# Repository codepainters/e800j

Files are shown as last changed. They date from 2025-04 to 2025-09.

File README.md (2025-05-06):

# Elwro 800 Junior replica

This repository contains all the necessary files to build a replica of [Elwro 800 Junior](https://pl.wikipedia.org/wiki/Elwro_800_Junior), a Polish home computer that can be considered a  [ZX Spectrum](https://en.wikipedia.org/wiki/ZX_Spectrum) clone. As of May 5, 2025, there are 3 successful builds, so the design files can be assumed valid.

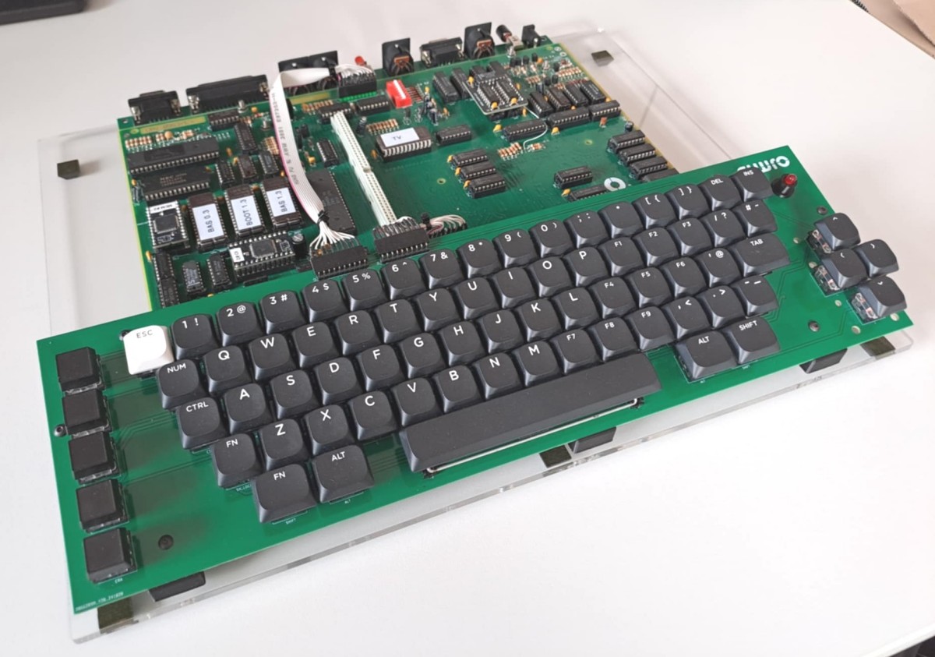
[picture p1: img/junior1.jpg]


## PCBs

The replica consists of three separate PCBs:

* [e800j_rev_c](e800j_rev_c) is the main board, an exact clone of the original *Elwro 800 Junior Rev C* PCB.  The original dimensions and mounting holes have been precisely recreated, making it suitable as a direct replacement for damaged original boards. 
* [kbd_cherry](kbd_cherry) is a replacement keyboard that uses standard Cherry MX switches. I chose not to replicate the original keyboard, as its switches are nearly impossible to source.
* [ports_pcb](ports_pcb) is a ports breakout board designed to simplify connections and avoid the mess of individual wires. This board is optional, but if you choose to connect ports with wires (as in the original design), you’ll need to derive the connections from the schematics.

All boards were designed in KiCad 9. In addition to the KiCad project files, each directory includes Gerber files, an interactive BOM, and PDF schematics. Refer to the respective subdirectories for assembly instructions and details.

### Additional documentation

* [pinouts](docs/pinouts.md) of the connectors
* [scans](docs/scans/) of the original schematics and DTR (*dokumentacja techniczno-ruchowa* - Polish for *technical reference manual*)
* [SCART](docs/scart.md) cable schematics / discussion

## Side projects

* Several side projects were created alongside the main replica (hosted in separate repositories):
* [e800j_addr_dec_gal](https://github.com/codepainters/e800j_addr_dec_gal) - replacement for address decoder PROMs using `GAL16V8` (original `74S474` PROMs are hard to get)
* [e800j_addr_dec_atf](https://github.com/codepainters/e800j_addr_dec_atf) - SMT variant using `ATF1502ASL`
* [e800j_grafix](https://github.com/codepainters/e800j_grafix) - a small add-on board that fixes graphics glitches present in the original Elwro design
* [JuDIM](https://github.com/codepainters/judim) - Junior Disk Manager, a small CLI tool for transferring files to/from `DSK` images (similar in principle to [cpmtools](https://www.moria.de/~michael/cpmtools/))

More to follow.

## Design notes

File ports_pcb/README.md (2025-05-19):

# Ports breakout PCB for the Elwro 800 Junior replica

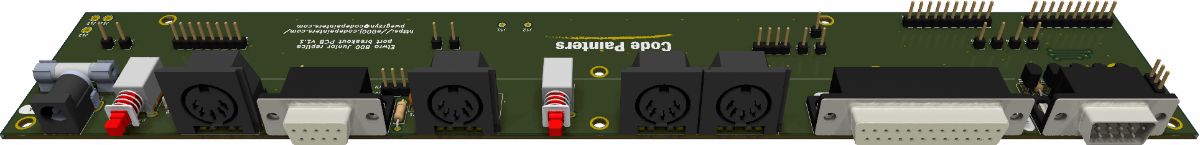
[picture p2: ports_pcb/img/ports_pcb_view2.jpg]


The idea behind this board is to simplify building the Junior replica (and not only that; read the notes section below), by using PCB-mounted connectors and switches, thus avoiding all the messy wire connections, as done in the original *Elwro 800 Junior*:

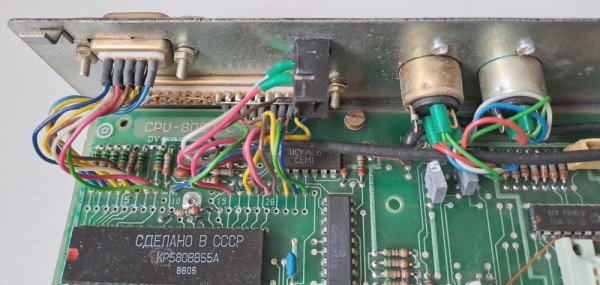
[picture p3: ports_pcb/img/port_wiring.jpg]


## Files

This directory contains the KiCAD 9 project, plus:

* schematics in PDF format - [color](ports_pcb.pdf) and [b&w](ports_pcb_bw.pdf)
* interactive [BOM](ports_pcb_ibom.html) (you need to download the file and open it locally) 
* [Gerber](gerbers) files (JLCPCB-compatible)

## Assembly

It's best to follow the interactive [BOM](ports_pcb_ibom.html).

### Options

There are some choices to be made:

* the original *Elwro* expects the joystick to short pins 1, 2, 3, 4 and 6 to `+5V` (and not to `GND`, as is usually done). 
  Because of this, pin 8 of the joystick connector is connected to the `+5V` rail.

  I decided to add 5 simple inverters (each consisting of a PNP transistor and a resistor) to make the port more standards-compliant 
  (allowing auto-fire joysticks to work as expected). With this modification pin 8 is tied to `GND`, pin 7 delivers `+5V` (via 
   a 27-ohm resistor on the mainboard), and pins 1, 2, 3, 4 and 6 react to shorting to ground.

  * If you want to use my mod, you need to:

    * assemble `T1..T5` transistors and `R1..R5` resistors

    * short pins 1 and 2 of `JP1` 

  * If you want to be 100% compatible with the original *Junior* instead:

    * solder jumpers instead of `R1..R5` resistors

    * solder jumpers between pins 1 and 2 of `T1..T5`

    * short pins 2 and 3 of `JP1`

* if a SCART cable is used, it is necessary to pull SCART's pin 16 (aka *Fast Blank*) above 1V to switch 
  the TV set to RGB signal. Unfortunately, Junior's RGB connector doesn't include a power pin, and there 
  are no spare pins to use. 

  I decided to make pin 8 of the RGB connector configurable between `SYN_H` and `+5V`, as the `SYN_H` signal is not necessary
  for SCART operation. Similarly, `SYN_V` is not really needed, so I've added `JP3` jumper allowing for disconnecting
  pin 6 and using it for other purposes. Also, `JP4` jumper allows for disconnecting `FON` signal from pin 7 (there's a plan to use pins 6 and 7 for stereo audio from AY-3-8910/12 card).

  So, if you want to use a SCART cable, you most likely want to:

  * assemble `C1` capacitor
  * put a jumper in place of  `R6` (the initial idea was to put a 180-ohm resistor there to limit the fast blank current, but now I think it's better to put it in the cable itself)
  * short pins 1 and 2 of `JP2`

  For a detailed explanation of the SCART issues  (as well as the cable schematics) , see [here](../docs/scart.md).

### Board stacking

The ports breakout PCB is designed to be mounted below the *Junior* main board and secured in place with M3 bolts. Corresponding pads on both the ports and main PCBs have the same labels (`J1` on the ports board should be connected to `J1` on the main board, `J2` to `J2`, etc.) and are positioned above each other (with 4 exceptions, see below), so they can be connected either by soldering short vertical wires (e.g., cut resistor pins, allowing for 5 mm spacing between the PCBs), or using "gold pin" connectors (requiring ~10 mm spacing). 

Here's how the boards look stacked together:

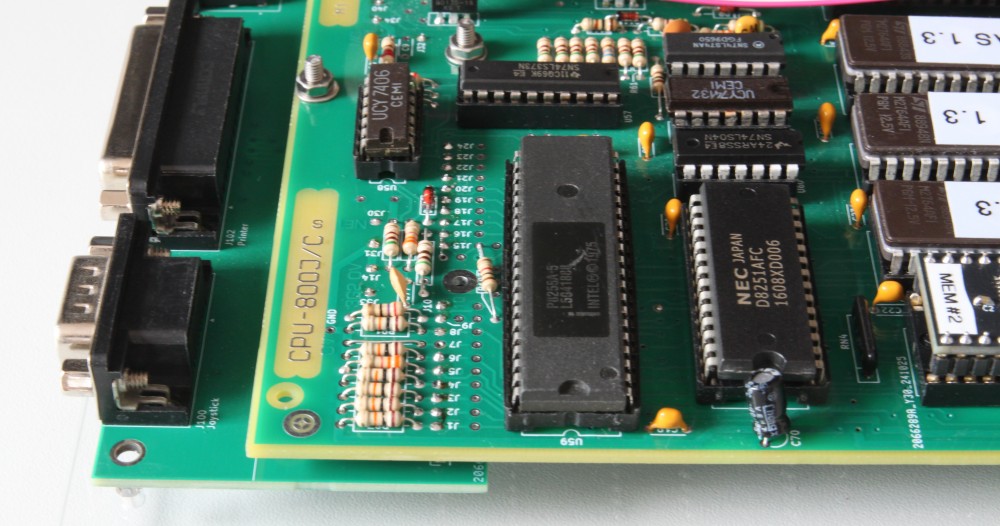
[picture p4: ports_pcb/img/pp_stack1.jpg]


Close-up of the connections:

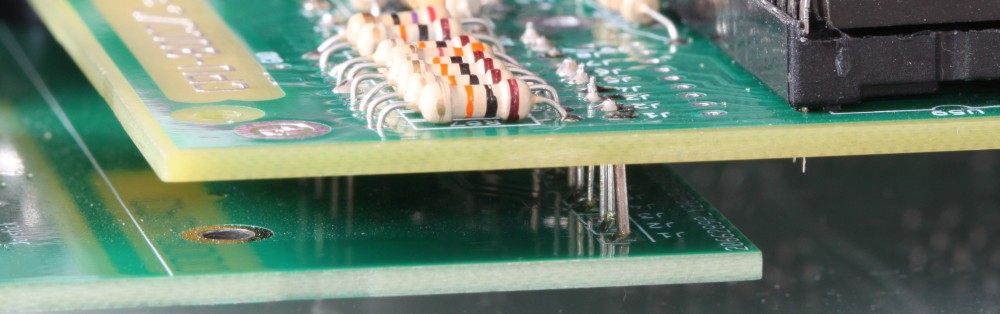
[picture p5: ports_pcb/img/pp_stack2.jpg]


There are the following exceptions that require short insulated wire connections (`J13` can be left unconnected):

* `J41` and `J42` - for the reset button
* `J11` and `J12` - `+5V` and `GND`, respectively

Close-up of the wire connections:

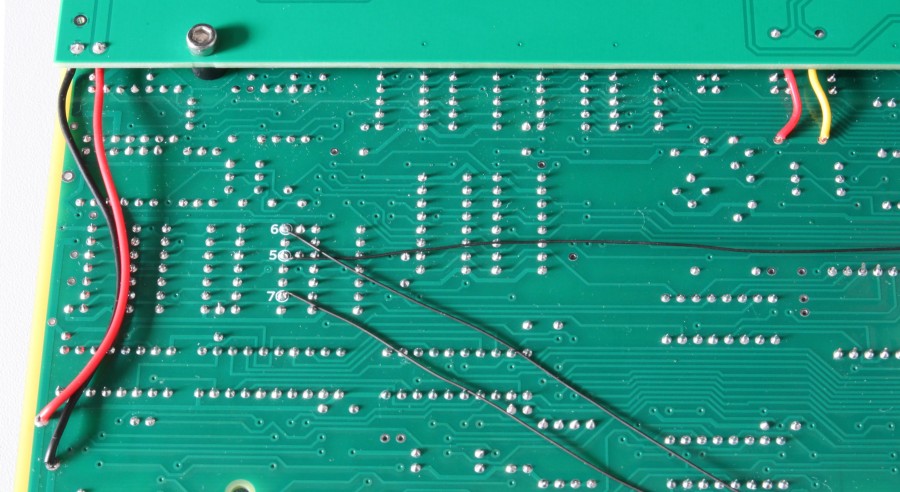
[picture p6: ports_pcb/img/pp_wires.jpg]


## Other Notes

Note that:

* *Elwro 800 Junior* uses a `DB37` connector for the printer, while my board uses the more common `DB25`. This saves a lot of space,
  and standard PC `DB25` printer cables are much easier to find.
* the fuse socket is optional, but I suggest using a fuse - better safe than sorry.

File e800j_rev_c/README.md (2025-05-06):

# Elwro 800 Junior replica - mainboard

This part of the project is the exact clone of the original *Elwro 800 Junior* PCB revision C. The PCB was reverse engineered from scanned images of the original PCB. All dimensions and mounting holes placements have been preserved, so the board can be used as a replacement for the original one.

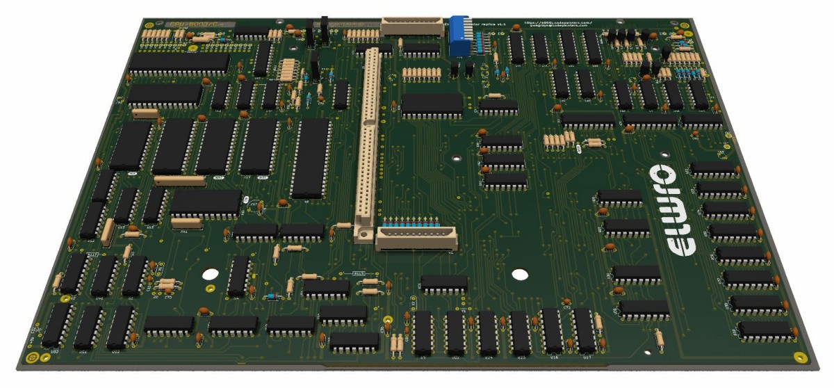
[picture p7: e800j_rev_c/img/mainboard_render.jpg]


Note: **Read this README file carefully**, it contains some important assembly instructions!

## Files

This directory contains the KiCAD 9 project, plus: 

* Schematics in PDF format - [color](pdfs/e800j_rev_c.pdf) and [b&w](pdfs/e800j_rev_bw.pdf) 
* [Gerber](gerbers) files (JLCPCB-compatible zip files)
* Interactive [BOM](e800j_rev_c_ibom.html) (you need to download the file and open it locally) 
* [scans](scans) of the original PCB used for reverse engineering

For files to be programmed into EPROMs, see [here](../roms).

Note: KiCAD PCB file still embeds the scanned images used for reverse engineering, so don't be surprised by the file size! The project passes PCB vs schematic parity check.

## Conventions

Schematics:

* For (hopefully) better readability, original schematic diagram has been split into separate blocks (total of 14 schematic sheets, mostly A4-size, with the exception of address decoder, DRAM, memory controller and video parts, which exceeded A4 size). I believe it's easier to analyze the schematic drawn in this manner. The PCB passes validation against schematic diagrams, so it can be assumed that the schematics are correct.
* In the top-level schematic sheet I decided to only draw some wires / buses between blocks. Global signals (like `MEMR`, or `IOR`) are only connected using labels, as the wires would clutter the drawing too much otherwise.
* Original schematics use somewhat unusual notation for signal names - prefixed with `+` or `-` sign for active-high (e.g. `+RELOK`) and active-low (e.g. `-MEMR`) signals, respectively. My schematic diagrams use standard notation with active-low signals with a bar above the name.
* Most of the signal names correspond directly to the original *Elwro* schematics, however some new signal names were added (mostly because of the cross-sheet connections). To differentiate them, upper-case names are used for signals from the original documentation, and lower-case is used for signal names introduced by me. 
* Original schematic uses "topological" reference designators for integrated circuits - the PCB is divided into numbered columns and rows marked with letters, and chip reference designators denote the chip placement, e.g. `J16`, `I5`, etc. I decided to use standard `U1, U2, ...` numbering, but original reference designators are stored as `OrigRef` attribute (also visible in the PCB editor in `User.Comments` layer). 
* Original design uses 2% `E48` series resistors for no good reason (most likely because of availability), my replica uses standard 5% `E24` series resistors. Original values are stored in the schematic as `OrigValue` attributes.
* Some IC types differ between *Elwro* documentation and the actual PCB used for reference. In such cases actual IC types as used on the board (e.g. Russian ones) are stored under `OrigType` attribute for cross-reference.

PCB:

* some connections on the board are made with pieces of wire (on top or bottom side of the PCB, the boards I used for reference has all these connections made on the top side, but I've seen original boards with wire connections made on the bottom side as well, I've chosen the bottom side for my build). In order to make the board pass schematic parity checks I have drawn these connections on `In1.Cu` and `In2.Cu` layers (typically used for 4-layer PCB projects).
* to make assembling easier the points that have to be connected are annotated with numbers on the bottom silkscreen layer, see the assembly instructions below.
* the original PCB contains some factory mods that involve cutting the traces. I decided to make the gaps on the PCB so no trace cutting is necessary (it is of course necessary to assemble other parts of the mods, see the assembly instructions).

## Assembling

### PCB variants

There are two variants of the Gerber files available:

* [e800j_rev_c_v1.1.zip](gerbers/e800j_rev_c_v1.1.zip) - a "modern" one, with tented vias and silkscreen (on both sides of the board!) - most likely what you want. The board manufactured from this set of files looks like this:

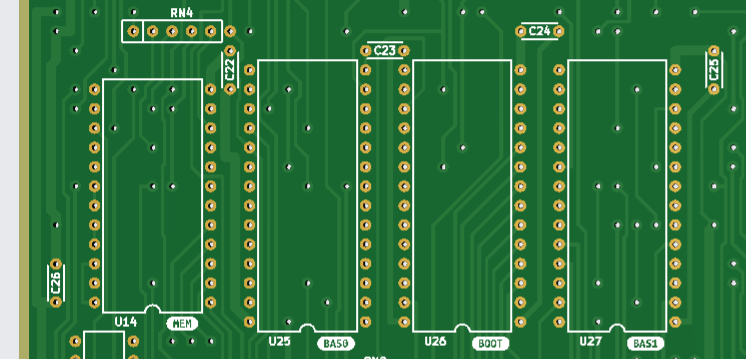
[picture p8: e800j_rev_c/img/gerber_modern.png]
  

* [e800j_rev_c_v1.1_retro.zip](gerbers/e800j_rev_c_v1.1_retro.zip) - a "retro" variant, without via tenting and silkscreen, which aims to look as much like the original PCB as possible (which might be useful for restoration projects):

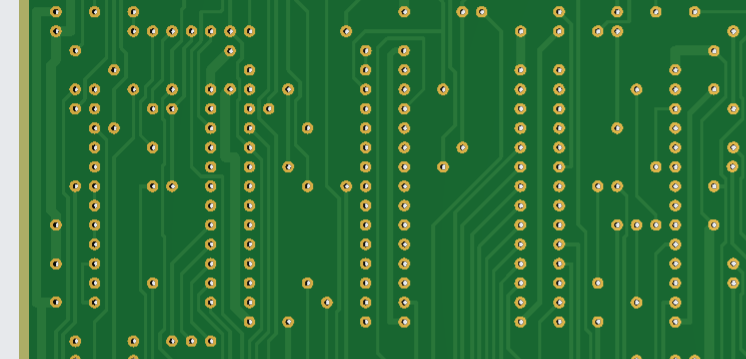
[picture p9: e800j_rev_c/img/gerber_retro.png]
  

Unless you specifically need the retro variant, I highly recommend the standard one, with tented vias and silkscreen - it makes assembly much easier.

### Part selection

Most of the parts used on the board are standard TTL 74xx chips, with some exceptions:

*  `74S474` 512x8 PROM memories, used in the I/O and memory address decoders, are hard to find and difficult to program. As part of the project, I've prepared two replacement options:
   *  [e800j_addr_dec_gal](https://github.com/codepainters/e800j_addr_dec_gal) - using `GAL16V8` PLD

   *  [e800j_addr_dec_atf](https://github.com/codepainters/e800j_addr_dec_atf) - using `ATF1502ASL` (if you prefer SMD chips)

		Both options have been verified to work properly.

* The `2716` EPROM (`U11` on the schematics, used to generate video signal timing) can be replaced with a `2732` memory (with the content doubled, see [roms](../roms) for the appropriate file).

* Some chips required replacement:
  * `U1`  - I had to replace a perfectly valid `74LS04` with another brand, as it didn't want to oscillate, eventually I got it working with a `UCY74LS04` from Cemi. Similarly, I had to replace the `U4` chip (`74LS04`) with `UCY74LS04` as well. These chips work in specific, semi-analog circuits, so the choice of actual chips might be important.
  * Initially, the computer was very picky about DRAM chips, only working properly with a few chips from my collection. As it turned out, replacing `U28..U31` (perfectly valid Motorola `74LS153` address multiplexers) with `SN74LS153N` from Texas Instruments solved the issue, and virtually every 4164 DRAM chip I could find works properly now.
  
* for `GT1` connector (used to plug-in floppy disk controller), you can use original Eltra 841 84-pin socket, if available. This is the recommended way if you want to use the original FDC (or a clone with an Eltra plug). Otherwise simple pin-header sockets will do (and pin headers work with Eltra 841 too. My future expansion PCBs are going to use pin headers):

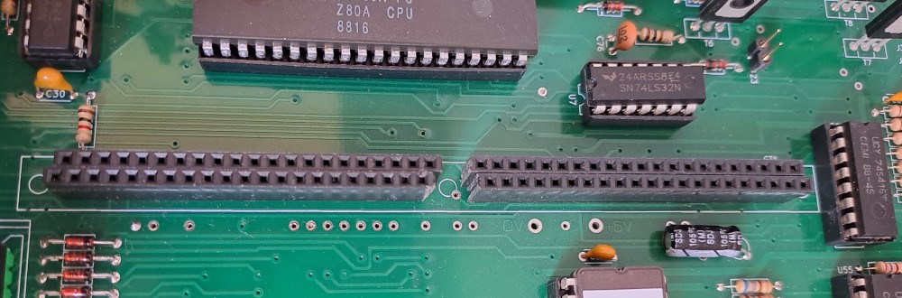
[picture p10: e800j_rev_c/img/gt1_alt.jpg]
  

* for keyboard connectors ( `W1` and `W2` ) one can use standard pin headers (10-pins long) - it works well with Eltra plugs. 

### PCB mods

I decided to fully replicate the original factory mods, to better match the look and feel of the PCB. 

Changes involve:

* Clock section - soldering `C83` (120pF) and `R118` (510 ohm)
* Memory controller - soldering `R119` (100 ohm)

The soldering points are marked with small dots on the silkscreen layer:

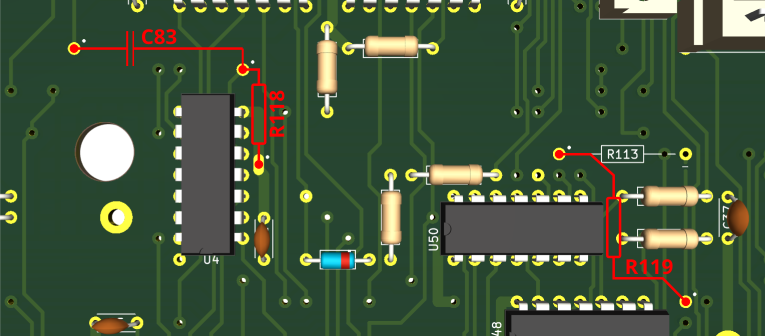
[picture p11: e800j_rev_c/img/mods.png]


### Wire connections

Finally, 11 wire connections are needed on the bottom of the PCB. Soldering points are numbered - connect `1` to `1`, `2` to `2` and so on.

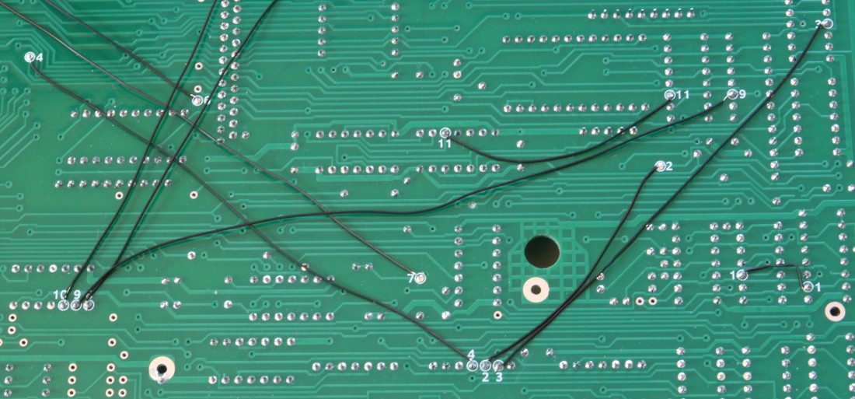
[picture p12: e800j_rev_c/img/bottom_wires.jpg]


## Bring-up 

If assembled from functional parts, the board requires no tuning and should work from the first power-up.

* for initial bring-up it's best to use monochrome composite video output (pad `J51`). If you can't get properly synchronized video, double-check `U19` (`2716` EPROM responsible for generating video timing signals). Some programmers (including my TL866A) are known to be occasionally problematic with 2716 memories, what sometimes helps is programming the memory twice (without erasing). 
* `U1` and `U4` chips might need replacement (see parts section above), in case of issues it's best to check the clock signals with an oscilloscope.
* if you observe random instabilities or persistent artifacts on the screen, replace `U28..U31` (again, see above for explanation).

That's all, folks!

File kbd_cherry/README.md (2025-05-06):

# Keyboard with Cherry MX switches

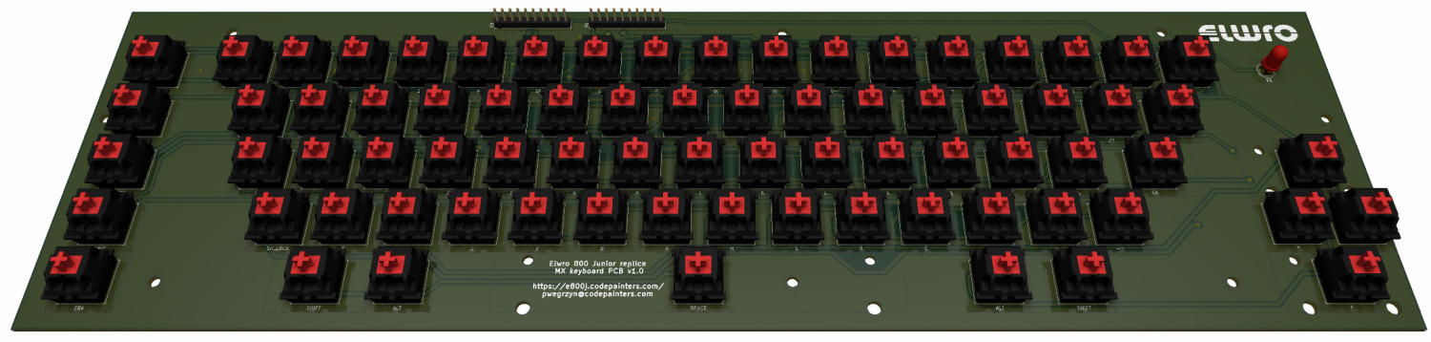
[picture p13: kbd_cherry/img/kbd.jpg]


Note:

* this PCB is **not a replacement** for the original keyboard PCB. The intention here was to create a keyboard for the replica, and not for restoration work. Original switches are nearly impossible to find, so there is little point in replicating the original board anyway.
* that said, the 10-pin connectors match the original pinout, so this PCB can be connected to the original PCB, for example for testing purposes.

* https://www.keyboard-layout-editor.com/ was used to create the layout. I decided to follow the keycap widths of the original keyboard which are slightly different from a typical PC keyboard (e.g., the  `TAB` key is only `1U` wide). There are many other differences, custom keycap labels are necessary anyway, so it doesn't bother me too much. 
* the spacebar requires a typical Cherry stabilizer to work properly (the PCB-mount variant). There are stabilizer holes around the `Up` and `Down` cursor keys as well, but that’s due to the footprint used, these keys don't actually need stabilizers.

This directory contains KiCAD 9 project, plus:

* schematics in PDF format - [color](kbd_cherry.pdf) and [b&w](kbd_cherry_bw.pdf)
* [keyboard-layout.json](docs/keyboard-layout.json) file for the https://www.keyboard-layout-editor.com/
* [layout](docs/keyboard-layout.png) diagram
* relevant [scans](docs/dtr) from the original Elwro documentation
* [Gerber](gerbers) files

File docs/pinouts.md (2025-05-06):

# Connectors

#### Power (`ports_pcb` only)

* 5.5/2.1 DC connector
* center pin `+5V` , outside `GND`

#### Printer (DB25)

Note: This is the pinout of the `DB25` variant, as used in `ports_pcb`. For the pinout of the original `DB37` connector, refer to the Elwro documentation.

| Pin | Name | Comment |
| ----- | --- | --- |
| 1 | `PRN_STRB` | `J10`, `PC7` output via double `7406` buffer |
| 2 | `D0` | `J18`, `PB0` output |
| 3 | `D1` | `J19`, `PB1` output |
| 4 | `D2` | `J20`, `PB2` output |
| 5 | `D3` | `J24`, `PB3` output |
| 6 | `D4` | `J23`, `PB4` output |
| 7 | `D5` | `J22`, `PB5` output |
| 8 | `D6` | `J21`, `PB6` output |
| 9 | `D7` | `J16`, `PB7` output |
| 10 | `PRN_ACK`  | `J15`, `PC2` input, 1k pull-up |
| 11-17 | - | |
| 18-25 | `GND` | |

#### Joystick (DB9)

| Pin  | Name | Comment |
| ---- | --- | --- |
| 1 | `UP` | `J2`, `PA3` input, |
| 2 | `DOWN` | `J4`, `PA2` input |
| 3 | `LEFT` | `J6`, `PA1` input |
| 4 | `RIGHT` | `J8`, `PA0` input |
| 5 | - | |
| 6 | `FIRE` | `J1`, `PA4` input |
| 7 | `+5V` | `J9` (`+5V` via 27 ohm resistor) |
| 8 | `+5V` / `GND` | `J5` (`PA6` with 3k3 pull-up) or `GND`* |
| 9 | - | |

Note:

* If you're not using `ports_pcb` (or using `ports_pcb` without joystick inverters), all inputs respond to being shorted to `J5` (pin 8), which is pulled up to `+5V`.
* If you're using `ports_pcb` with inverters, pin 8 is at `GND`, and all inputs respond to being shorted to ground.

#### Tape (DIN-5)

| Pin  | Name | Comment |
| ---- | --- | --- |
| 1 | `TAPE_OUT` | `J33`, output to tape recorder.  |
| 2 | `GND` | Ground. |
| 3 | `TAPE_IN`  | `J35`, input from tape recorder. |

#### Junet (DIN-5)

| Pin  | Name | Comment |
| ---- | --- | --- |
| 1 | `DATA_NET`  | Serial data.  |
| 2 | `GND` | Ground. |
| 3 | `CLK_NET` | Serial clock. |
| 4 | `/BUSY_NET` | Busy flag. |
| 5 | - | Not used. |

Both sockets are connected in parallel (Junet is a bus, not a ring).

#### Video (aka MONITOR, DIN-5)

| Pin  | Name | Comment |
| ---- | --- | --- |
| 1 | `/LUM` | `J51`, composite video (monochrome). |
| 2 | `GND`  | `J52`, ground. |
| 3 | `FON`  | `J53`, audio signal, same as RGB connector pin 7. |

#### RGB (DB9)

| Pin  | Name | Comment |
| ---- | --- | --- |
| 1 | `GND` | `J43` |
| 2 | `/SYNC` | `J44` |
| 3 | `R` | `J45`, 0 - 2.5V |
| 4 | `G` | `J46`, 0 - 2.5V |
| 5 | `B` | `J47`, 0 - 2.5V |
| 6 | `BRIGHT` | `J48` TTL levels |
| 7 | `FON` | `J53`, audio signal, same as `Video` connector pin 3. |
| 8 | `SYN_H` or `+5V` | `J49` or `+5V`, configurable on `ports_pcb` (`JP2`).  |
| 9 | `SYN_V`* | `J50`, configurable on `ports_pcb` (`JP3`). |

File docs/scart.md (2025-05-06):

# SCART cable 

## I just want to connect my TV

Junior allows the monitor to be connected in two ways:

- via the DIN-5 connector labeled `MONITOR` (`J103` on the ports PCB, marked as `Video`) – pin 1 of this connector provides a CVBS signal, but it is monochrome only
- via the DB-9 connector labeled `RGB` (`J101` on the ports PCB), which provides digital RGB signals

The second connector allows Junior to be connected to a TV with SCART input, but a small modification is required – you need to route 5V to pin 9 of the RGB connector. For the original Junior, the easiest way is to cut the wire between the mainboard and pin 9, then connect pin 9 to any +5V point on the mainboard. If you're using my [ports_pcb](../../ports_pcb), it's enough to set the `JP2` jumper accordingly.

Next, you need to use a cable built according to this schematic:

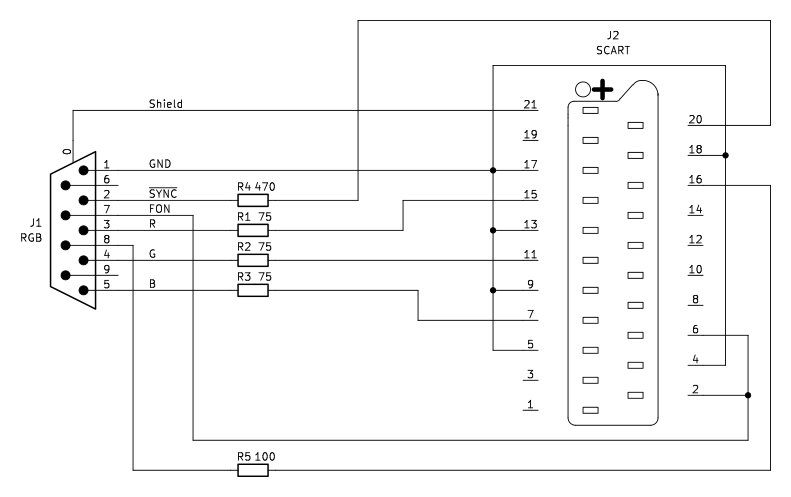
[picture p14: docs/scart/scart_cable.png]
SCART cable


The cable will also work without the resistors, but with them, the voltage levels at the SCART input are closer to standard, and current consumption is noticeably lower.

### But... where are my colors?

The above solution is not ideal — it only allows for displaying 8 colors, whereas Junior (like the ZX Spectrum) supports a palette of 15 colors. To correctly display all colors, the `BRIGHT` signal (pin 6 of the `RGB` connector) must also be taken into account. However, a simple resistor-based solution did not yield satisfactory results.

A similar issue applies to the Commodore 128 and CGA graphics cards. While many solutions can be found online, they won’t work correctly with the Junior due to its somewhat non-standard voltage levels (the `R`, `G`, and `B` signals only reach 2.5V). A dedicated solution for the Junior is currently in development.

## Long story

Probably the most popular monitor for Juniors nowadays is a TV with a SCART connector, usually connected using a cable made according to a schematic that was once published on his (now defunct) website by Krzysztof Komarnicki:

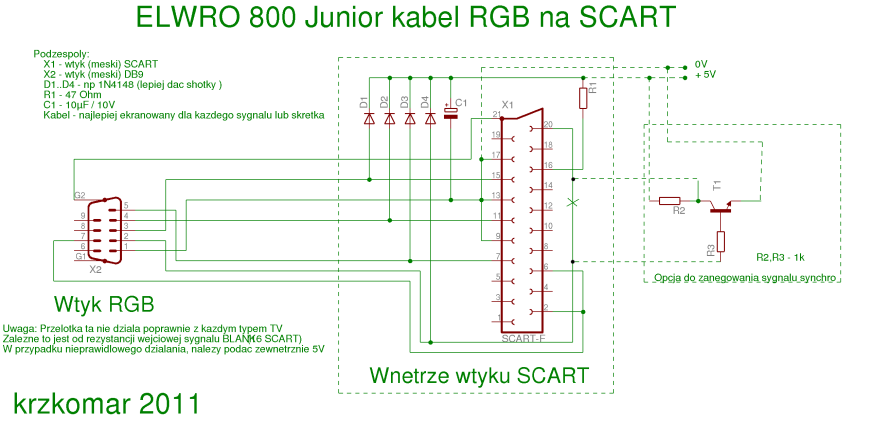
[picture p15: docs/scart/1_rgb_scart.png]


A cable built according to this schematic works, allowing a color image to be displayed on the TV screen:

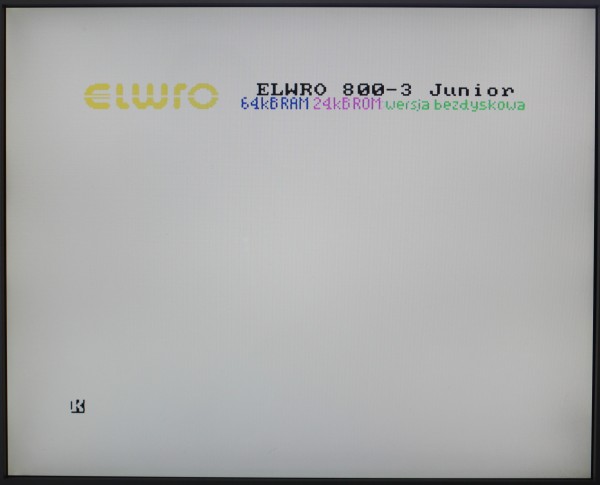
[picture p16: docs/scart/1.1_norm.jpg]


According to the note on the schematic, this solution doesn’t work correctly with every type of TV. Based on my observations, fully correct operation is rather rare.

### Problem No. 1 – Voltage on SCART Pin 16 Too Low

It's enough to set the border color of the image to black using the `BORDER 0` command to see the first issue – clearly visible problems with horizontal synchronization in the section containing the logo, as well as a bright band and distorted text in the border area at the bottom of the screen.

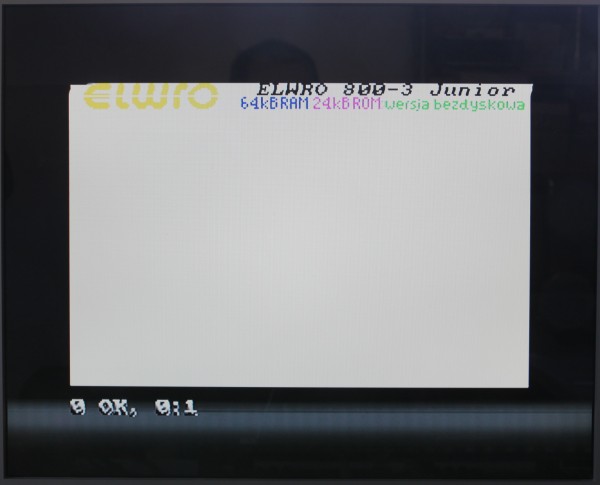
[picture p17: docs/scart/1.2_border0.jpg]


To understand exactly what's happening, let's start by redrawing the schematic into a clearer form, taking into account the input impedance of the SCART connector.

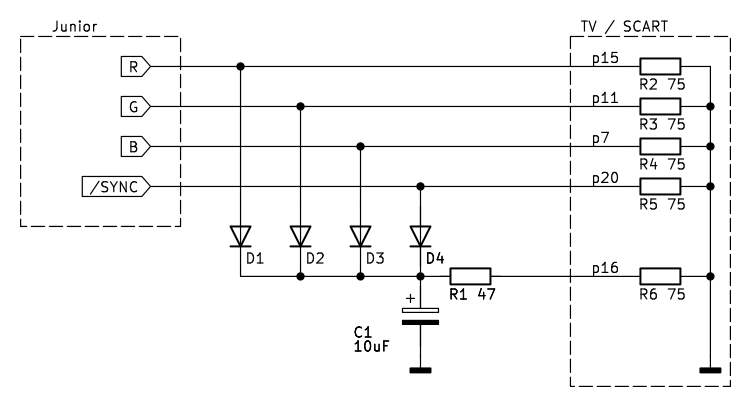
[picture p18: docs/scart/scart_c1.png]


Pin 16 of the SCART connector is used to switch the TV between RGB and CVBS signals; this signal is often referred to as *fast blank* (as opposed to pin 8 – *slow blank* – which switches the TV to the SCART input and selects between 4:3 or 16:9 format). According to the `BS EN 50049-1:1998` standard, a voltage above 1V selects the RGB signal.

The circuit consisting of diodes `D1` to `D4`, capacitor `C1`, and resistor `R1` is designed to generate the appropriate voltage by "stealing" current from the signal lines. However, when the image consists mainly of dark areas, the circuit fails to work properly – the voltages on the `R`, `G`, and `B` lines are close to zero, and the `/SYNC` signal level itself is too low (under a 75-ohm load it reaches only about 1.2V, which is insufficient even if a Schottky diode were used):

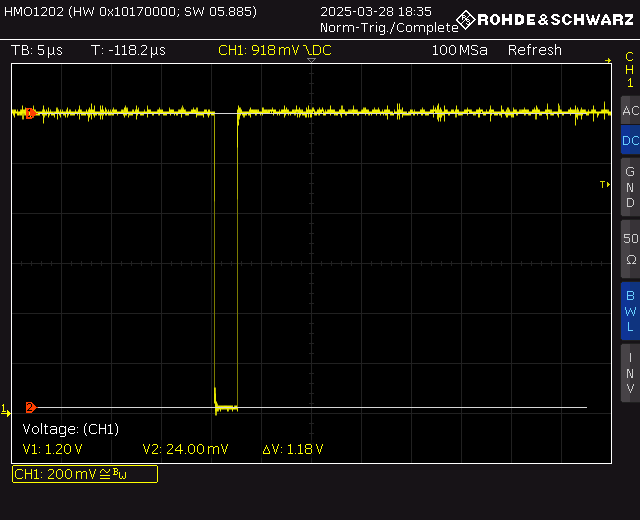
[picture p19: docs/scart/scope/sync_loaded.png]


As a result, capacitor `C1` quickly discharges through the 75-ohm impedance of SCART pin 16, which can be confirmed by connecting the oscilloscope to pin 16:

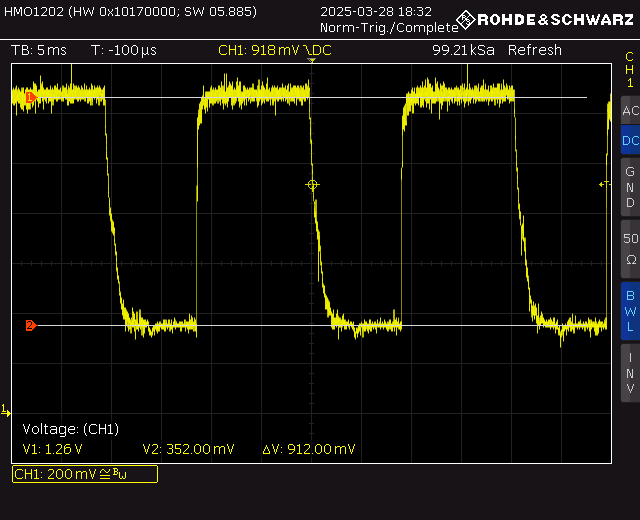
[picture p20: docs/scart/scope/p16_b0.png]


### Problem No. 2 – Horizontal Synchronization

Let’s try, as an experiment, connecting pin 16 to an external 5V power source, and adding a 75-ohm resistor as a load to the diode-based circuit:

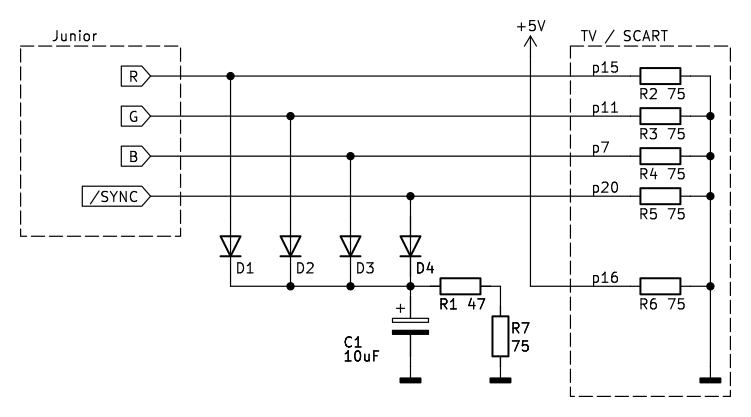
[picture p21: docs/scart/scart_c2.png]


With this setup, the image looks significantly better, though synchronization issues are still visible in the section with the logo:

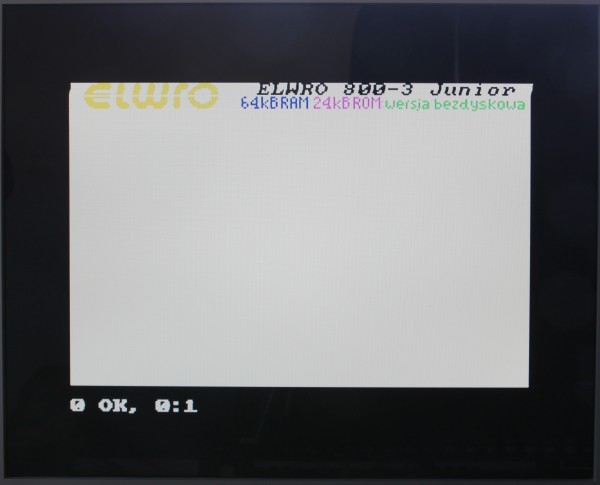
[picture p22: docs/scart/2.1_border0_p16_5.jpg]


This is caused by the load imposed on the `/SYNC` signal by the circuit — after the black section of the top border, capacitor `C1` is discharged, which results in current flowing through diode `D4`. This, in turn, causes the synchronization pulse to become distorted. 

To summarize, the diode-based trick simply cannot work correctly. For this reason, I recommend supplying +5V to the `RGB` connector and using a cable built according to the schematic shown above.

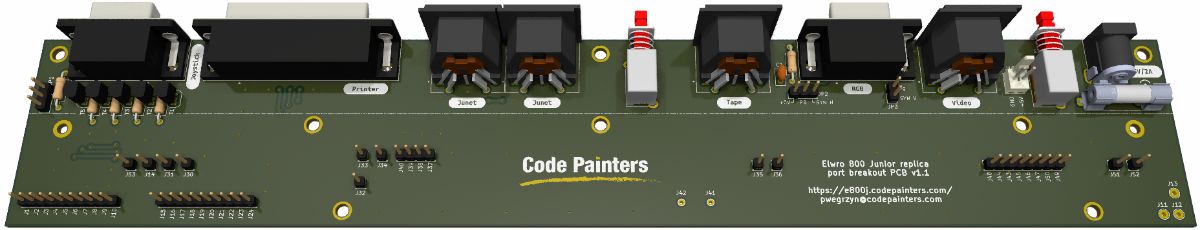
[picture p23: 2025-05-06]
ports_pcb/img/ports_pcb_view1.jpg

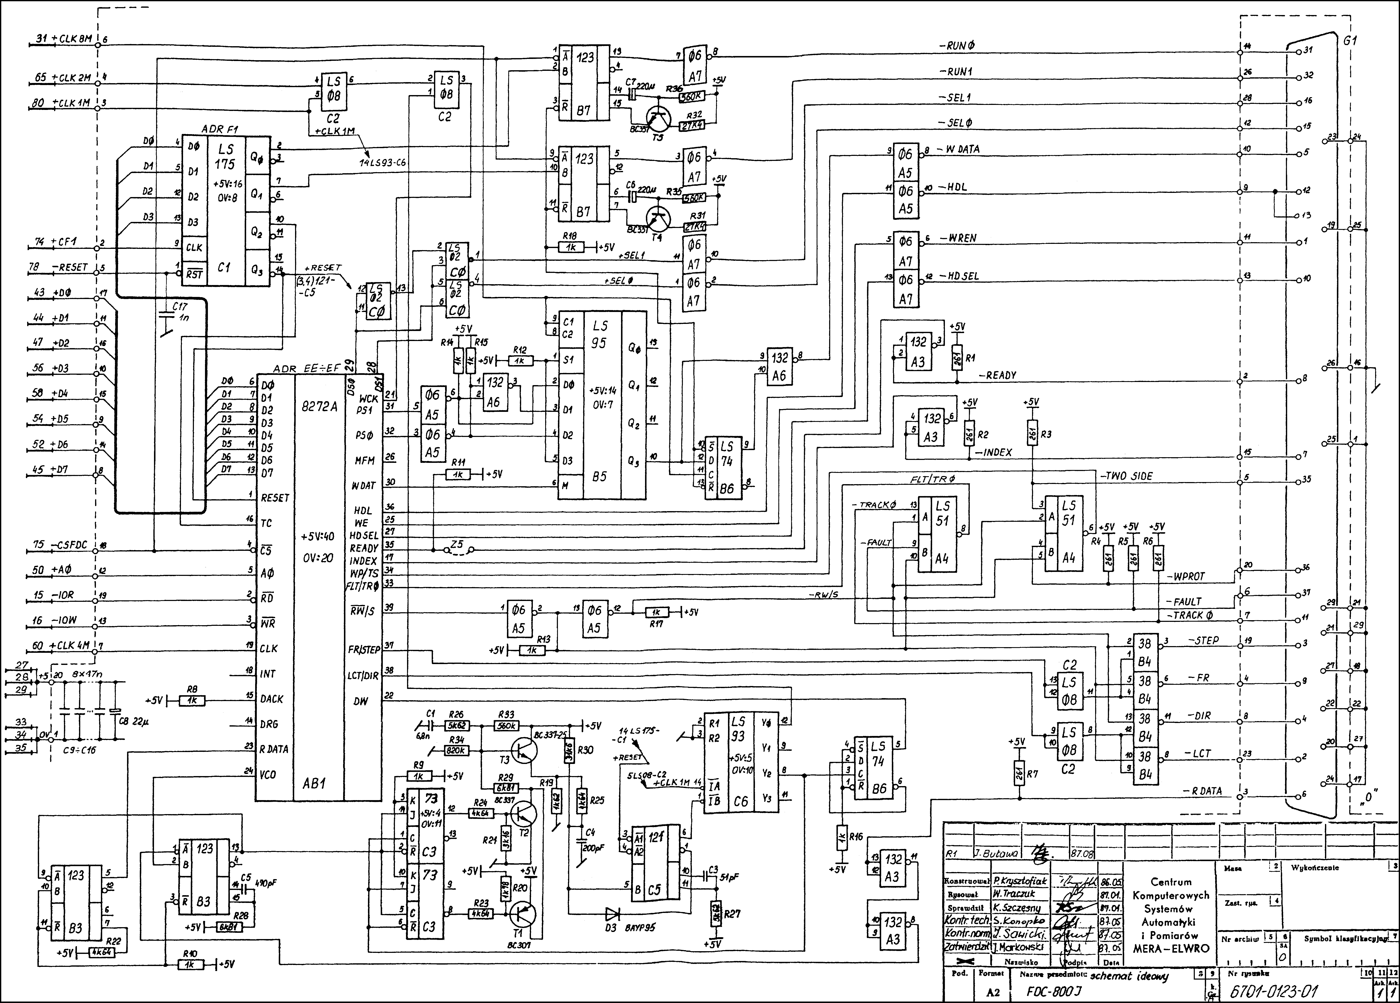
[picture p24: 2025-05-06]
docs/scans/fdc-800j.gif

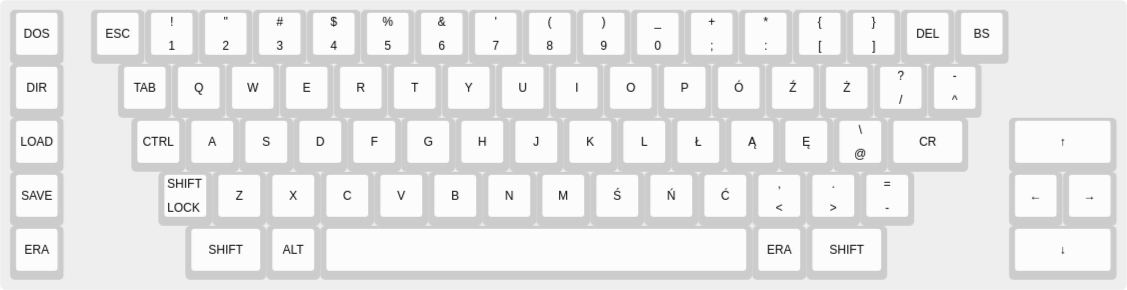
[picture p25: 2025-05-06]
kbd_cherry/docs/keyboard-layout.png

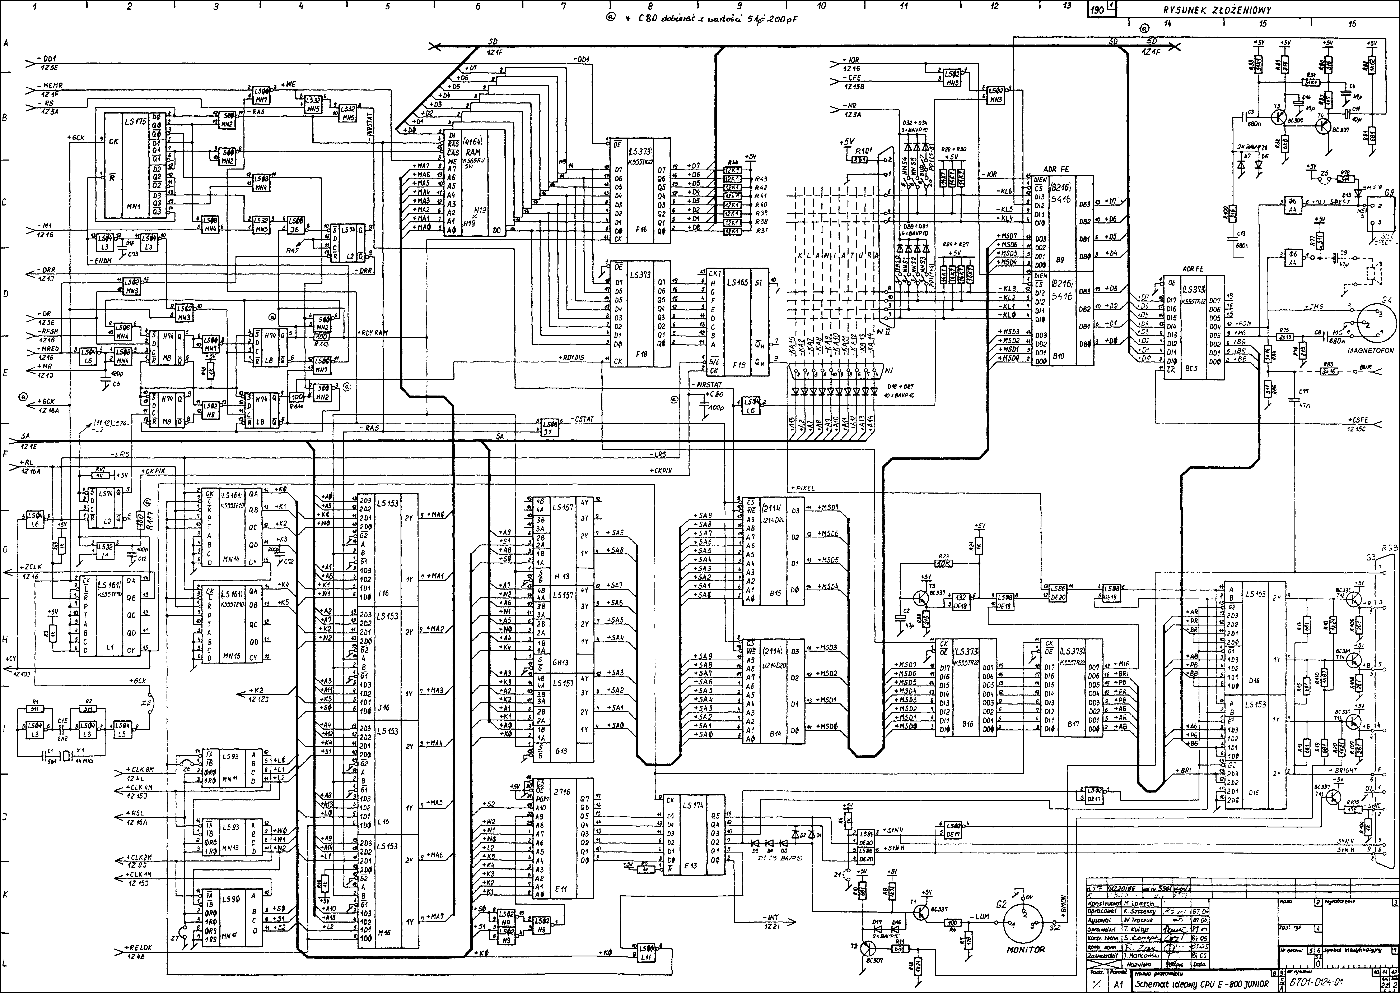
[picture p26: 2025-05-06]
docs/scans/cpu800j2.gif

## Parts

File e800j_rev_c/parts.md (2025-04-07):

Integrated cicuits
------------------------

| Ref.des. | Orig. des. | Type | Actual type | Description |
| --- | --- | --- | --- | --- |
| U11 | A4 | 7406 | | 6 inverters, open-collector |
| U34 | B9 | M8216 | UCY74S416 | 4-bit bidirectional bus driver |
| U35 | B10 | M8216 | UCY74S416 | 4-bit bidirectional bus driver |
| U60 | B14 | 2114 | U214D20 | 1024x4 static RAM |
| U61 | B15 | 2114 | U214D20 | 1024x4 static RAM |
| U62 | B16 | 74LS373 | K555IR22 | Octal latch, 3-state outputs |
| U63 | B17 | 74LS373 | K555IR22 | Octal latch, 3-state outputs |
| U12 | BC2 | 8255 | | Parallel I/O |
| U13 | BC5 | 74LS373 | K555IR22 | Octal latch, 3-state outputs |
| U64 | D15 | 74LS153 | | Dual 4-input multiplexer |
| U65 | D16 | 74LS153 | | Dual 4-input multiplexer |
| U14 | DE2 | 8251 | KR580WW51A  | USART |
| U15 | DE4 | 74LS04  | | 6 inverters |
| U16 | DE5 | 74132 | | 4x 2-input NAND, Schmitt trig. |
| U17 | DE6 | 74LS74  | | Dual D-type Flip-Flop |
| U18 | DE8 | 74LS32  | | 4x 2-input OR gate |
| U66 | DE17 | 74LS02  | | 4x 2-input NOR gate |
| U67 | DE18 | 74132 | | 4x 2-input NAND, Schmitt |
| U68 | DE19 | 74LS08  | | 4x 2-input AND gate |
| U69 | DE20 | 74LS86  | | 4x 2-input XOR gate |
| U36 | E11 | 2716 | | 2kB EPROM |
| U37 | E13 | 74LS174 | | Hex D Flip-Flop |
| U70 | F16 | 74LS373 | K555IR22 | Octal latch, 3-state outputs |
| U71 | F18 | 74LS373 | K555IR22 | Octal latch, 3-state outputs |
| U72 | F19 | 74LS165 | | 8-bit PISO shift register |
| U19 | G1/2 | 74S474  | | 512 bytes PROM (MEM RT5) |
| U20 | G3 | 2764 | K573RF4 | 8kB EPROM (BAS0) |
| U21 | G4/5 | 2764 | K573RF4 | 8kB EPROM (BOOT) |
| U22 | G5 | 2764 | K573RF4 | 8kB EPROM (BAS1) |
| U38 | G13 | 74LS157 | | Quadruple 1-of-2 multiplexer |
| U39 | GH13 | 74LS157 | | Quadruple 1-of-2 multiplexer |
| U23 | GH7 | Z80A | | CPU |
| U40 | H13 | 74LS157 | | Quadruple 1-of-2 multiplexer |
| U52..59  | H19..N19 | 4164 x8 | K565RU5W x8 | 64kx1 DRAM (8 pcs) |
| U3 | I1 | 74LS32  | | 4x 2-input OR gate |
| U24 | I5 | 74S474  | | 512 bytes PROM (MEM RT5) |
| U48 | I16 | 74LS153 | | Dual 4-input multiplexer |
| U6 | J1 | 7438 | | Quad 2-input NAND, open col. |
| U7 | J2 | 74LS175 | | Quad D Flip-Flop |
| U8 | J3 | 74LS85  | | 4-bit magnitude comparator |
| U9 | J6 | 74LS00  | | 4x 2-input NAND gate |
| U10 | J7 | 74LS08  | | 4x 2-input AND gate |
| U49 | J16 | 74LS153 | | Dual 4-input multiplexer |
| U2 | L1 | 74LS161 | K555IE10 | Synchronous 4-bit counter |
| U4 | L2 | 74LS74  | | Dual D-type Flip-Flop |
| U1 | L3 | 74LS04  | | 6 inverters |
| U5 | L6 | 74LS04  | | 6 inverters |
| U33 | L8 | 74LS74  | | Dual D-type Flip-Flop |
| U41 | L11 | 74LS00  | | 4x 2-input NAND gate |
| U50 | L16 | 74LS153 | | Dual 4-input multiplexer |
| U31 | M8 | 74LS74  | | Dual D-type Flip-Flop |
| U51 | M16 | 74LS153 | | Dual 4-input multiplexer |
| U26 | MN2 | 74S00 | | 4x 2-input NAND gate |
| U27 | MN3 | 74LS02  | | 4x 2-input NOR gate |
| U28 | MN4 | 74LS08  | | 4x 2-input AND gate |
| U29 | MN5 | 74LS32  | | 4x 2-input OR gate |
| U30 | MN7 | 74LS00  | | 4x 2-input NAND gate |
| U25 | MN1 | 74LS175 | | Quad D Flip-Flop |
| U42 | MN10 | 74LS04  | | 6 inverters |
| U43 | MN11 | 74LS93  | | 4-bit binary counter |
| U44 | MN12 | 74LS90  | | Decade counter |
| U45 | MN13 | 74LS93  | | 4-bit binary counter |
| U46 | MN14 | 74LS161 | K555IE10 | Synchronous 4-bit counter |
| U47 | MN15 | 74LS161 | K555IE10 | Synchronous 4-bit counter |
| U32 | N9 | 74LS02  | | 4x 2-input NOR gate |

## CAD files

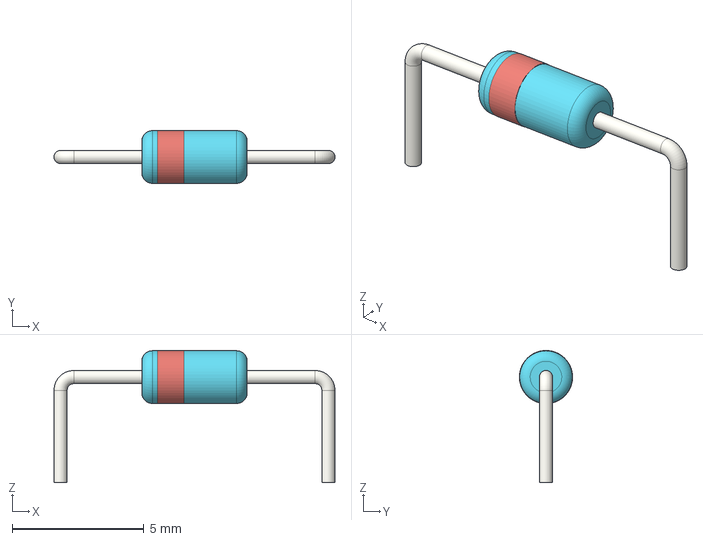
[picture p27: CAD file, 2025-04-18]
e800j_rev_c/3d/D_DO-35_SOD27_P10.16mm_Horizontal.step
10.7 x 2.02 x 5.01 mm

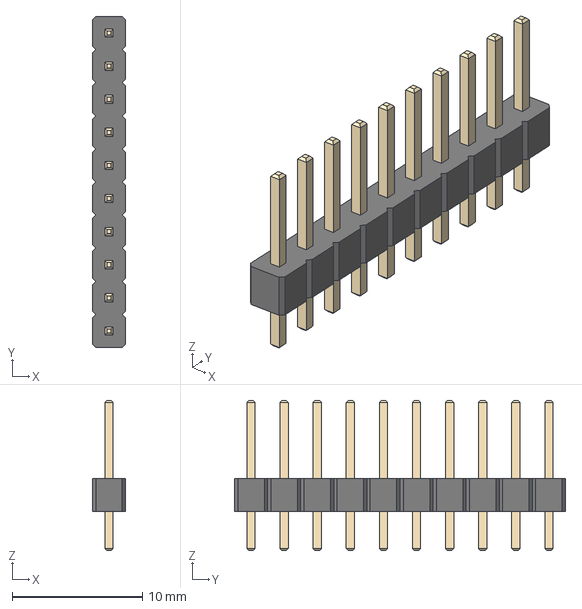
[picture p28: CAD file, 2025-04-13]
kbd_cherry/3d/PinHeader_1x10_P2.54mm_Vertical.step
2.54 x 25.4 x 11.5 mm

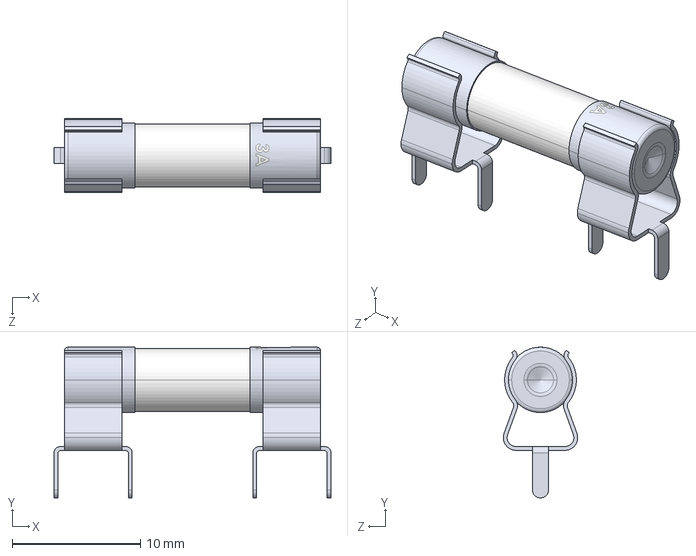
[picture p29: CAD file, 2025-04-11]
ports_pcb/3d/FuseHolder.step
21.6 x 11.8 x 5.80 mm
Fuse Clip x 2
3A Fuse

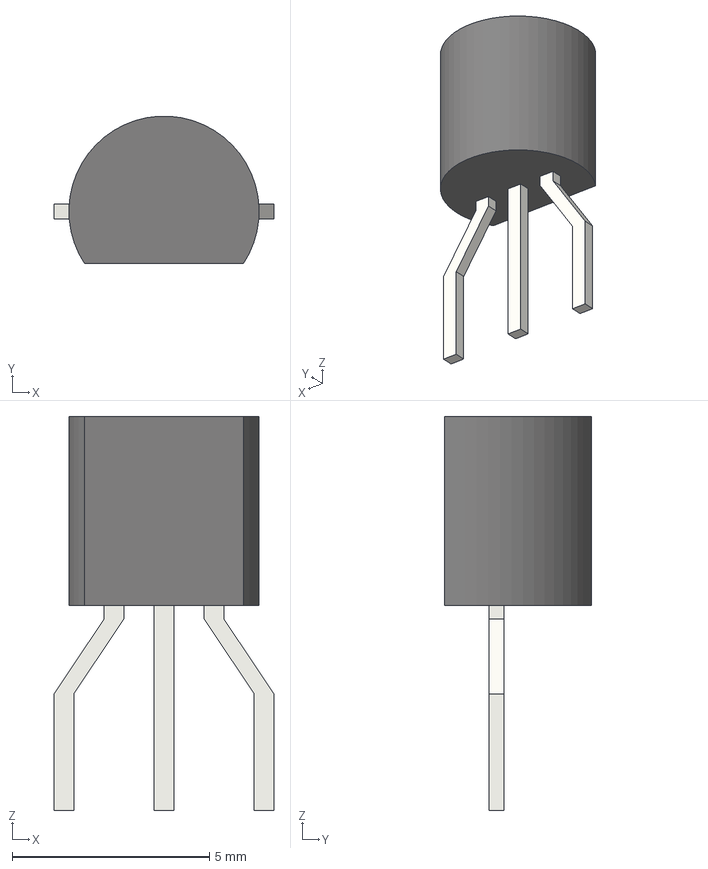
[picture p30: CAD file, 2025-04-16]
e800j_rev_c/3d/TO-92_Inline_Wide.step
5.58 x 3.74 x 10.0 mm

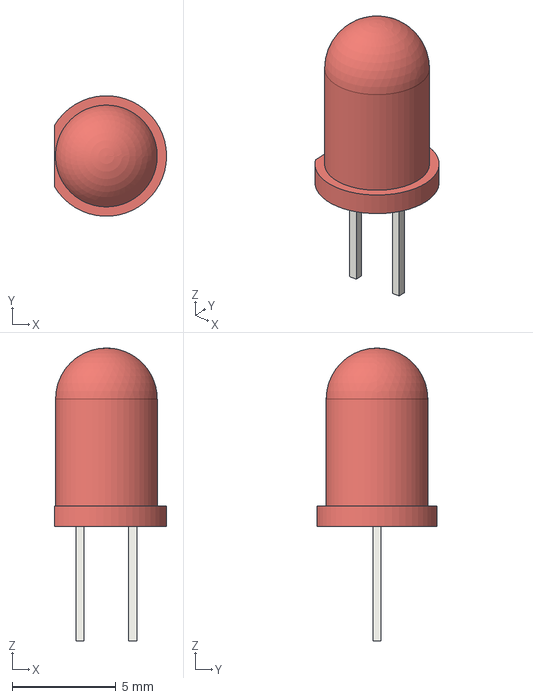
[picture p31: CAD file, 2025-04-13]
kbd_cherry/3d/LED_D5.0mm.step
5.40 x 5.79 x 14.1 mm

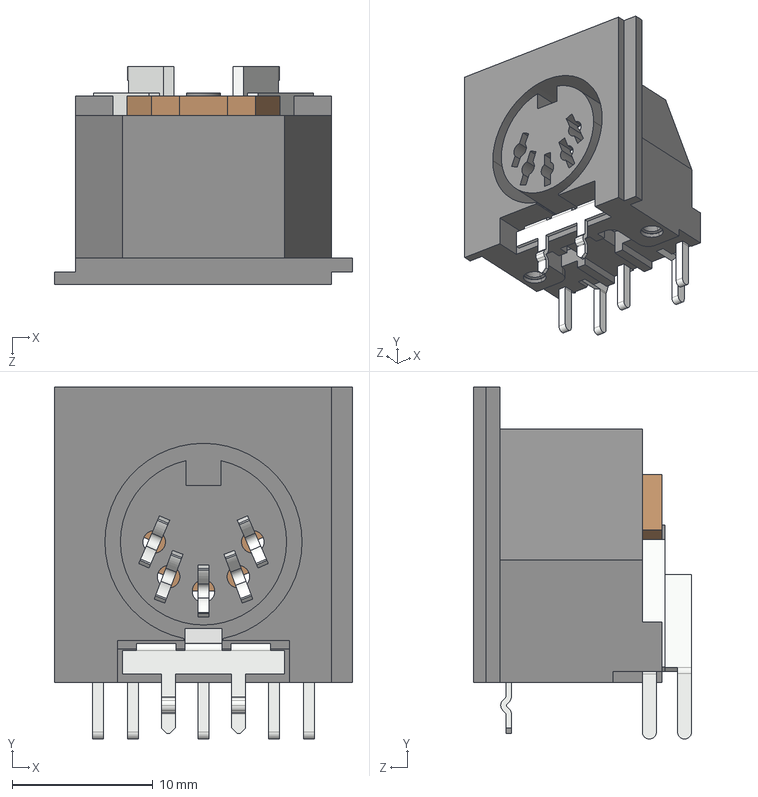
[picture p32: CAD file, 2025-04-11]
ports_pcb/3d/DIN5_PCB_DELTRON_671-0500.step
21.2 x 25.0 x 15.5 mm
DIN5_PCB_DELTRON_BODY
DIN5_PCB_DELTRON_PIN2
DIN5_PCB_DELTRON_PIN5
DIN5_PCB_DELTRON_PIN3
DIN5_PCB_DELTRON_PIN4
DIN5_PCB_DELTRON_PIN1
DIN5_PCB_DELTRON_FIX
DIN5_PCB_DELTRON_SHIELD

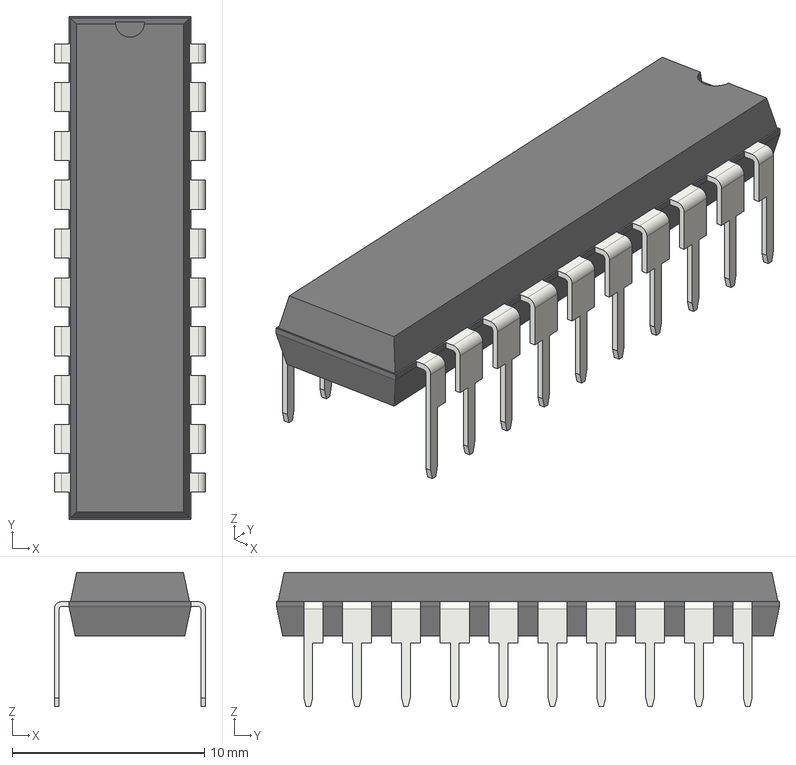
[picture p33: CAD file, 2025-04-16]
e800j_rev_c/3d/DIP-20_W7.62mm.step
7.87 x 26.2 x 6.98 mm

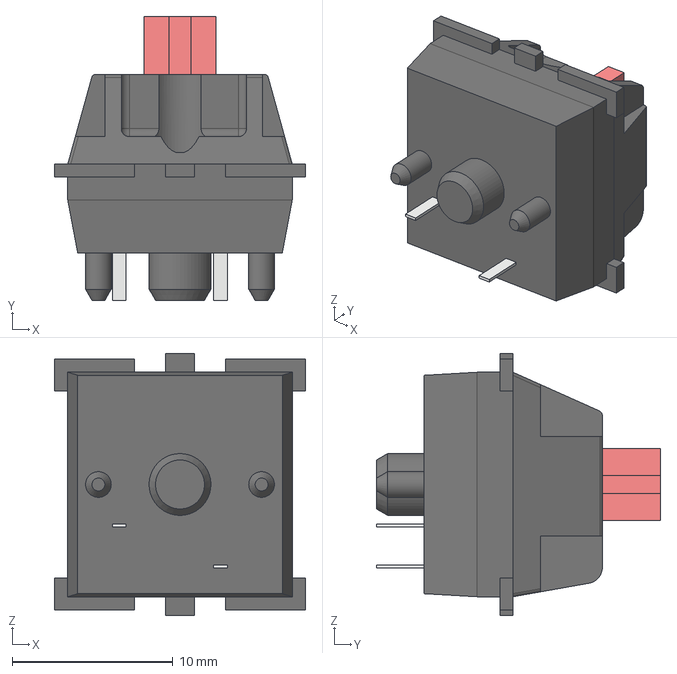
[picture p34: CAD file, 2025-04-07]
kbd_cherry/3d/switch.step
15.6 x 17.7 x 16.3 mm

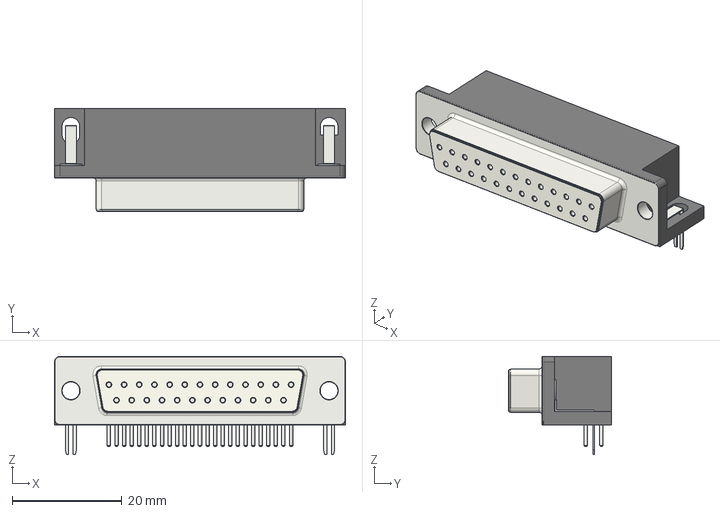
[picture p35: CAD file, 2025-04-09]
ports_pcb/3d/DSUB-25_Female_Horizontal_P2.77x2.84mm_EdgePinOffset7.70mm_Housed_MountingHolesOffset9.12mm.step
53.1 x 18.7 x 17.9 mm

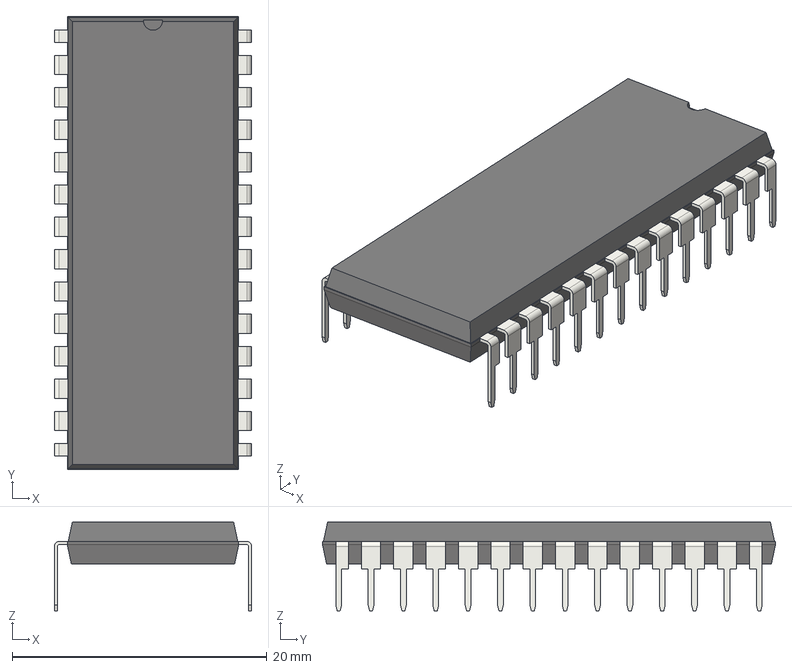
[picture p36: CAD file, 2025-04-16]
e800j_rev_c/3d/DIP-28_W15.24mm.step
15.5 x 35.6 x 6.98 mm

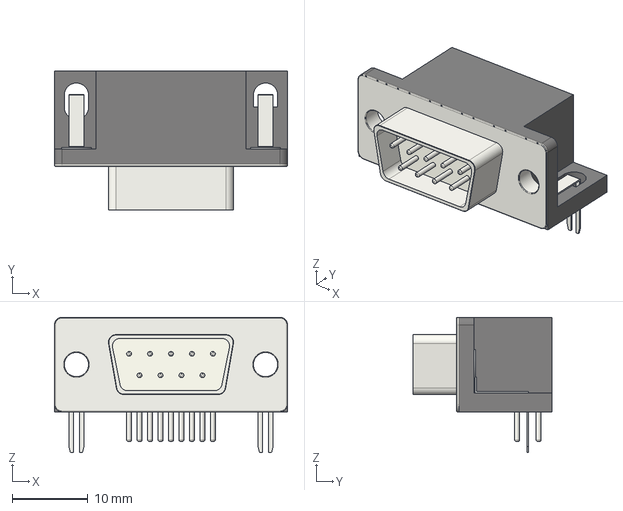
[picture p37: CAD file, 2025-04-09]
ports_pcb/3d/DSUB-9_Male_Horizontal_P2.77x2.84mm_EdgePinOffset7.70mm_Housed_MountingHolesOffset9.12mm.step
30.8 x 18.4 x 17.9 mm

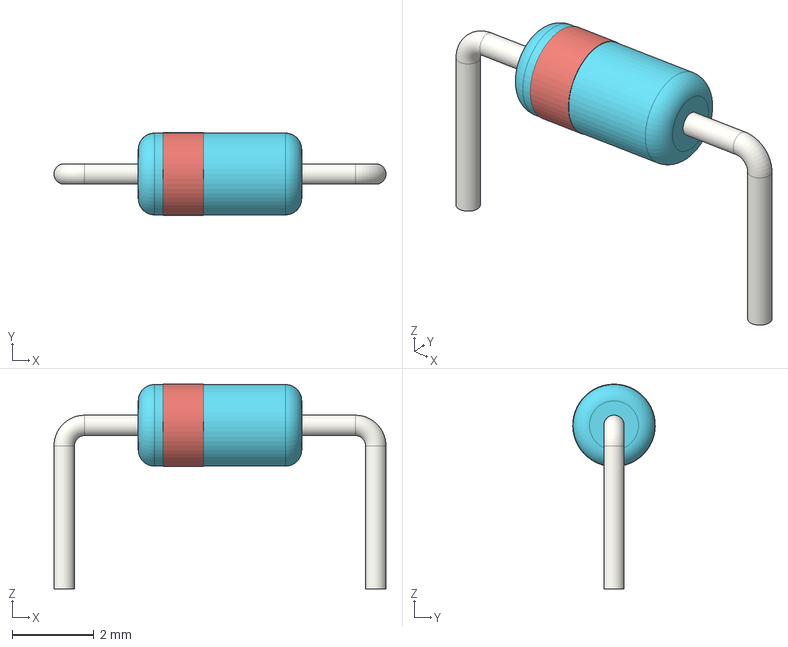
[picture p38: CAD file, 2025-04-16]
e800j_rev_c/3d/D_DO-35_SOD27_P7.62mm_Horizontal.step
8.12 x 2.02 x 5.01 mm

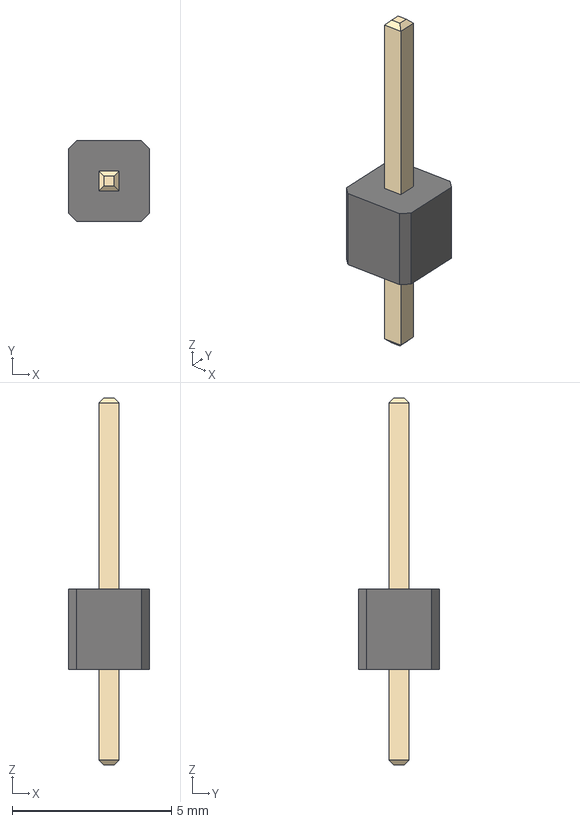
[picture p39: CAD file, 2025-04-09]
ports_pcb/3d/PinHeader_1x01_P2.54mm_Vertical.step
2.54 x 2.54 x 11.5 mm

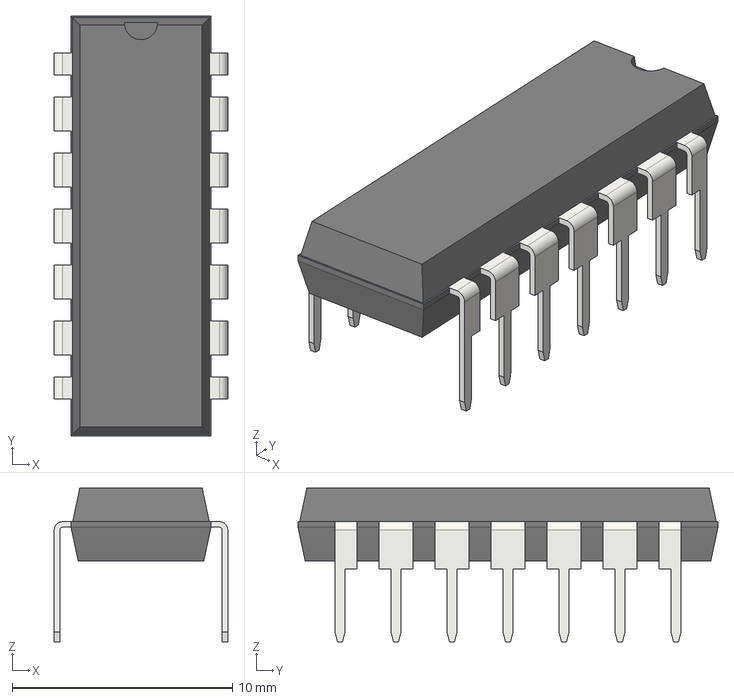
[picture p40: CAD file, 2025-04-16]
e800j_rev_c/3d/DIP-14_W7.62mm.step
7.87 x 19.1 x 6.98 mm

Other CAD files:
ports_pcb/3d/DSUB-9_Female_Horizontal_P2.77x2.84mm_EdgePinOffset7.70mm_Housed_MountingHolesOffset9.12mm.step
e800j_rev_c/3d/R_Array_SIP9.step
ports_pcb/3d/PS-22F03.step
e800j_rev_c/3d/C_Disc_D3.0mm_W1.6mm_P2.50mm.step
e800j_rev_c/3d/C_Disc_D4.3mm_W1.9mm_P5.00mm.step
e800j_rev_c/3d/DIP-16_W7.62mm.step
e800j_rev_c/3d/DIP-18_W7.62mm.step
e800j_rev_c/3d/DIP-24_W15.24mm.step
e800j_rev_c/3d/DIP-40_W15.24mm.step
e800j_rev_c/3d/R_Array_SIP5.step
e800j_rev_c/3d/R_Axial_DIN0204_L3.6mm_D1.6mm_P7.62mm_Horizontal.step
e800j_rev_c/3d/R_Axial_DIN0207_L6.3mm_D2.5mm_P10.16mm_Horizontal.step
e800j_rev_c/3d/R_Axial_DIN0309_L9.0mm_D3.2mm_P12.70mm_Horizontal.step
e800j_rev_c/3d/SW_DIP_SPSTx08_Piano_10.8x21.88mm_W7.62mm_P2.54mm.step
e800j_rev_c/3d/TO-126-3_Vertical.step
e800j_rev_c/3d/do-35.stp
e800j_rev_c/3d/eltra841.step
e800j_rev_c/3d/gwp10.step
ports_pcb/3d/DCJ200-10-A-K1-K.step

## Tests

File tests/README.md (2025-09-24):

# Tests

This directory contains Z80 assembly source code for various ad-hoc tests. You'll need `make` and [zasm](https://k1.spdns.de/Develop/Projects/zasm/Distributions/) to build them (just run `make` without any params). Resulting `.rom` files can be written to a 2764 EPROM (place it in the `BAS0` EPROM socket).

Test files:
- [01_color_bars.asm](01_color_bars.asm) - displays 15 vertical color bars with black screen border (useful for video output debugging).
- [02_color_bars2.asm](02_color_bars2.asm) - variation of the pervious test - the bars switch brightness in the middle.

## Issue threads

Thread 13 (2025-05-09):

ports_pcb: possibility to disconnect audio (FON) from RGB connector

codepainters, 2025-05-09:
As in the title. I've added the jumper on pin 9 for additional audio channel, but we want to reroute *primary* too!

codepainters, 2025-05-19:
Done.

Closed 2025-05-19.

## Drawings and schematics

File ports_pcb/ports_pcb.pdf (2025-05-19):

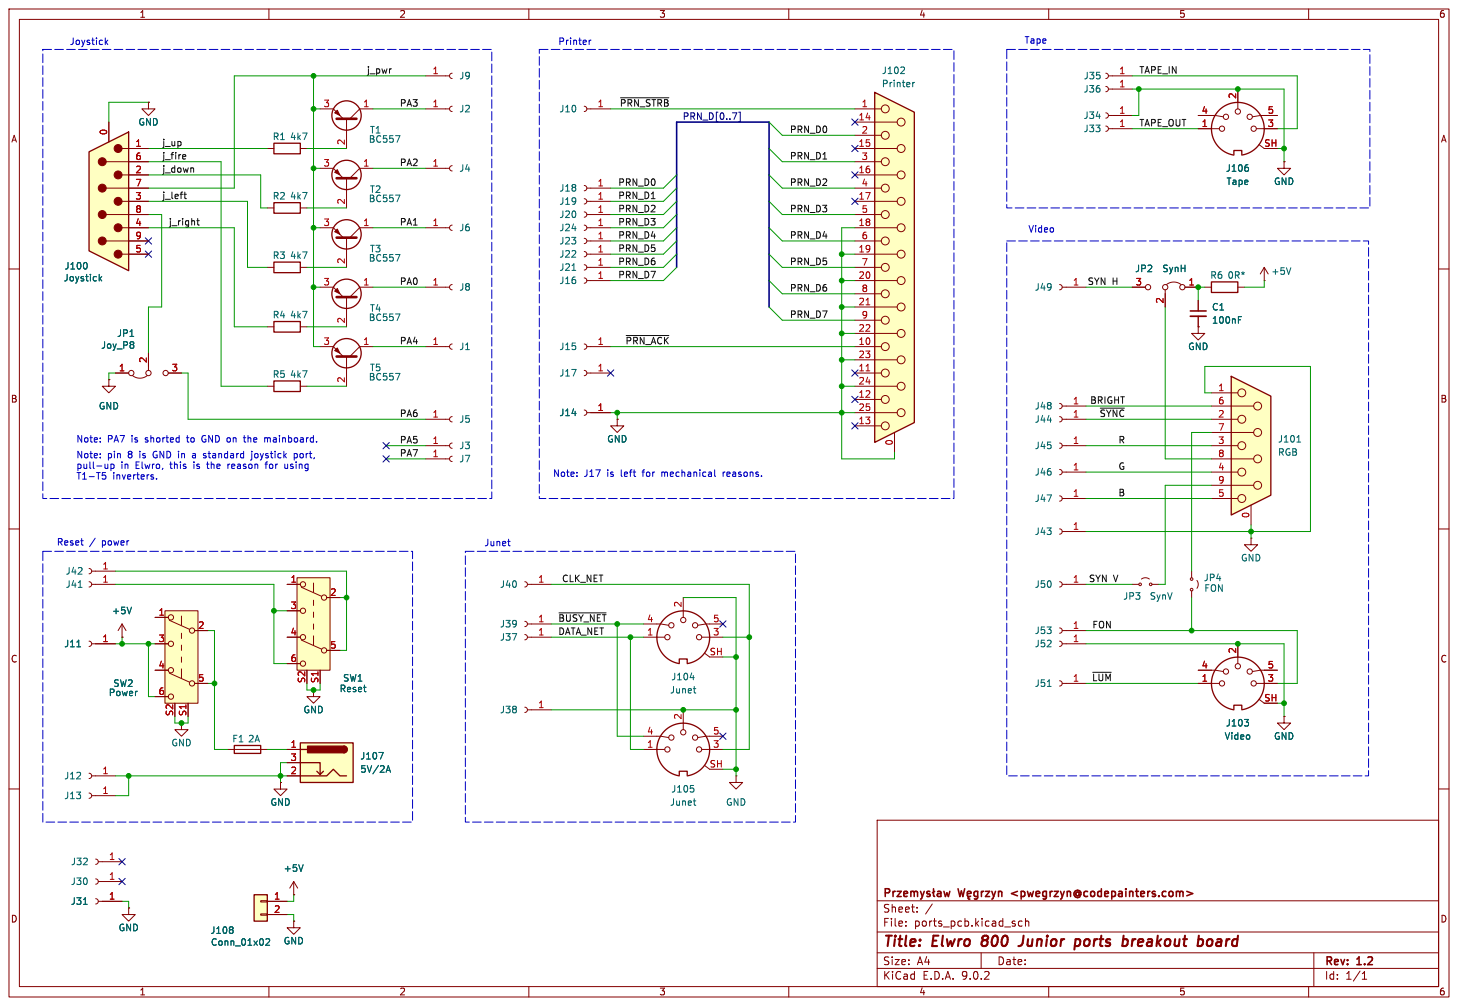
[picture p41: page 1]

Id: 1/1 Title: Elwro 800 Junior ports breakout board

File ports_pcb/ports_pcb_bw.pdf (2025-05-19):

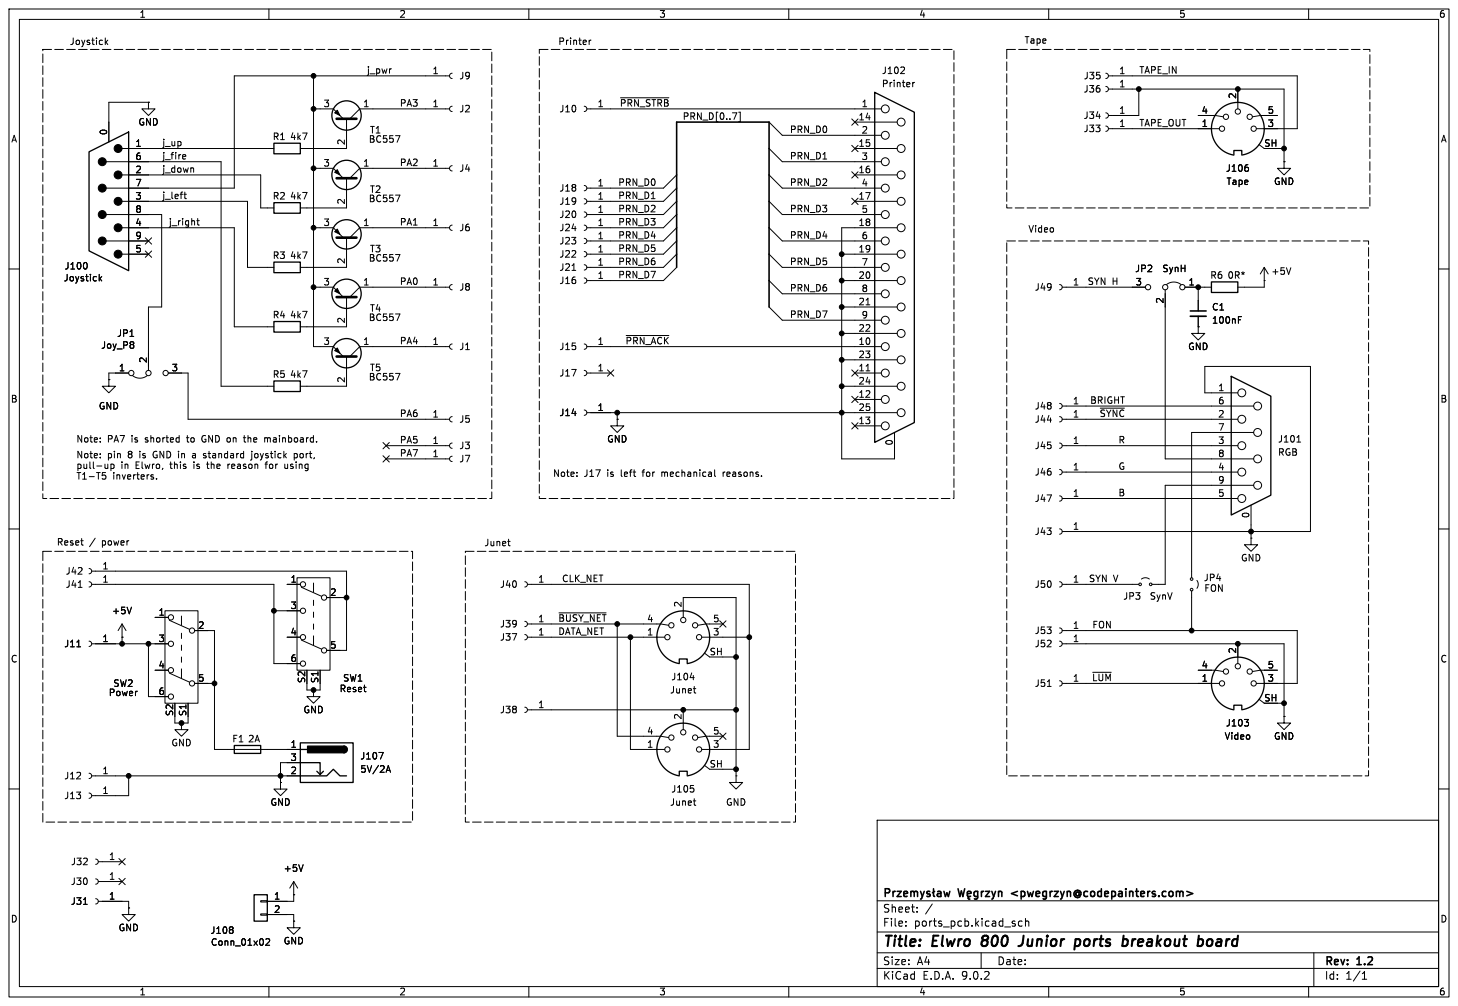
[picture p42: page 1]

File: ports_pcb.kicad_sch Sheet: / þÿPrzemysBaw þÿWgrzyn <pwegrzyn@codepainters.com> 1

Id: 1/1 Title: Elwro 800 Junior ports breakout board

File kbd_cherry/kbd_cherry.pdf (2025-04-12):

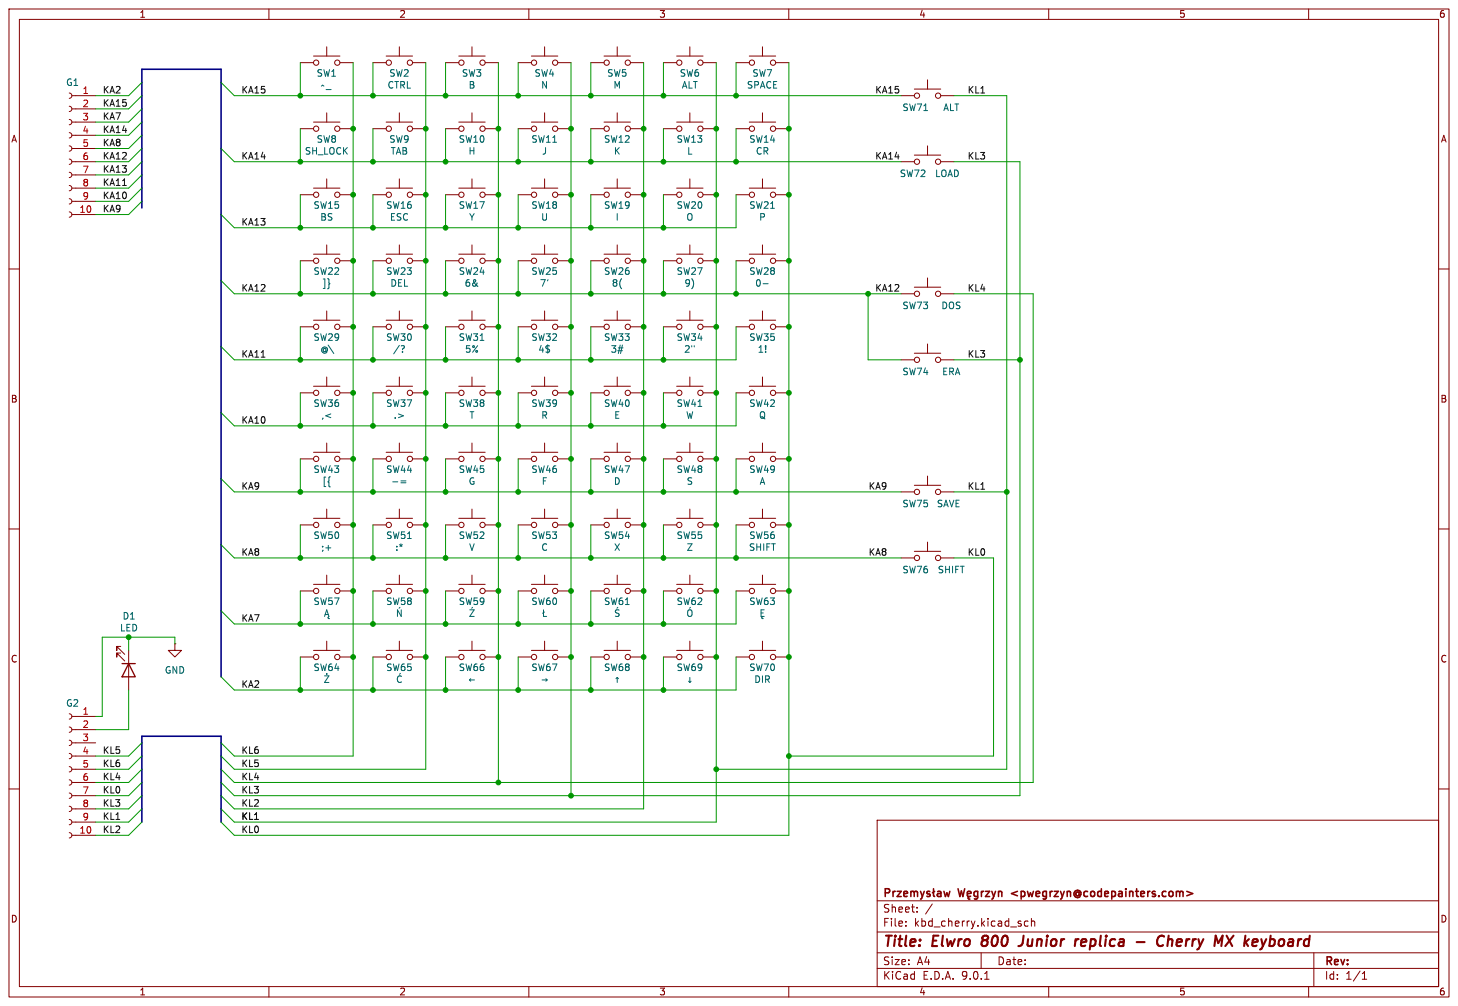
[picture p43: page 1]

File: kbd_cherry.kicad_sch Sheet: / þÿPrzemysBaw þÿWgrzyn <pwegrzyn@codepainters.com>

Id: 1/1 Title: Elwro 800 Junior replica - Cherry MX keyboard

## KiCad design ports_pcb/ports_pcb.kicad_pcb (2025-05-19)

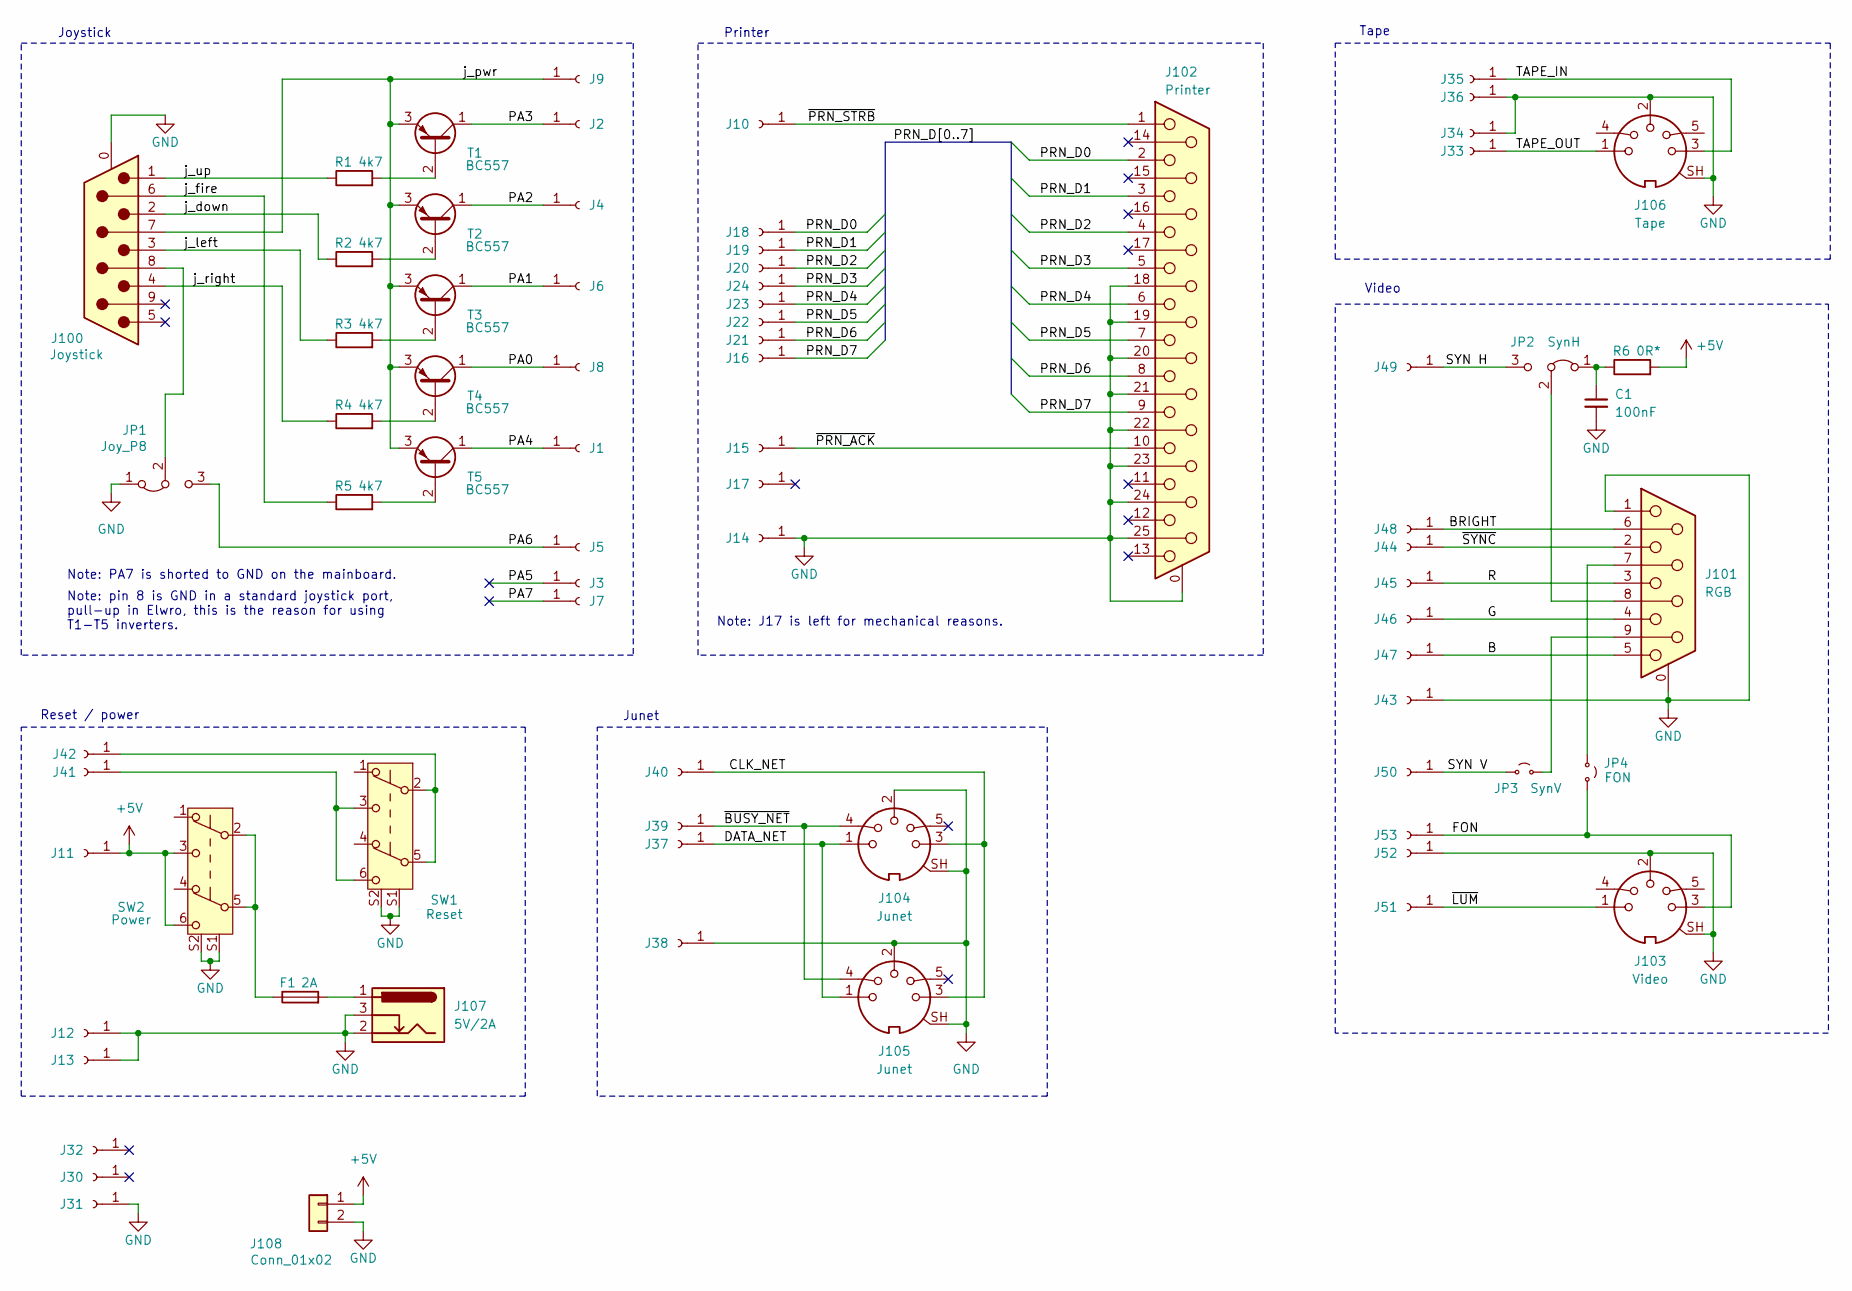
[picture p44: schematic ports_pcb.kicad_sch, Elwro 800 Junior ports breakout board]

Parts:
C1: 100nF; C_Disc_D5.0mm_W2.5mm_P2.50mm
F1: 2A; Fuseholder_Clip-5x20mm_Littelfuse_445-030_Inline_P20.50x5.2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
J1, J2, J3, J4, J5, J6, J7, J8, J9, J10, J14, J15, J16, J17, J18, J19, J20, J21, J22, J23, J24, J30, J31, J32, J33, J34, J35, J36, J43, J44, J45, J46, J47, J48, J49, J50, J51, J52, J53: Conn_01x01_Socket; PinHeader_1x01_P2.54mm_Vertical
J11, J12, J13: Conn_01x01_Socket; pin24
J37, J38, J39, J40: PinHeader_1x01_P2.54mm_Vertical
J41: RESET1; pin
J42: RESET2; pin
J100: Joystick; DSUB-9_Pins_Horizontal_P2.77x2.84mm_EdgePinOffset7.70mm_Hou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
J101: RGB; DSUB-9_Socket_Horizontal_P2.77x2.84mm_EdgePinOffset7.70mm_H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
J102: Printer; DSUB-25_Socket_Horizontal_P2.77x2.84mm_EdgePinOffset7.70mm_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
J103: Video; CUI_SDS-50J
J104, J105: Junet; CUI_SDS-50J
J106: Tape; CUI_SDS-50J
J107: 5V/2A; BarrelJack_GCT_DCJ200-10-A_Horizontal
J108: Conn_01x02; Molex_KK-254_AE-6410-02A_1x02_P2.54mm_Vertical
JP1: Joy_P8; PinHeader_1x03_P2.54mm_Vertical
JP2: SynH; PinHeader_1x03_P2.54mm_Vertical
JP3: SynV; PinHeader_1x02_P2.54mm_Vertical
JP4: FON; PinHeader_1x02_P2.54mm_Vertical
R1, R2, R3, R4, R5: 4k7; R_Axial_DIN0207_L6.3mm_D2.5mm_P10.16mm_Horizontal
R6: 0R*; R_Axial_DIN0207_L6.3mm_D2.5mm_P10.16mm_Horizontal
SW1: Reset; PS-22F03
SW2: Power; PS-22F03
T1, T2, T3, T4, T5: BC557; TO-92_Inline

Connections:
+5V: J11.1, J108.1, R6.2, SW2.3 (C), SW2.6 (C)
/B: J47.1, J101.5
/BRIGHT: J48.1, J101.6
/CLK_NET: J40.1, J104.3, J105.3
/DATA_NET: J37.1, J104.1, J105.1
/FON: J53.1, J103.3, JP4.1 (A)
/G: J46.1, J101.4
/PA0: J8.1, T4.1 (C)
/PA1: J6.1, T3.1 (C)
/PA2: J4.1, T2.1 (C)
/PA3: J2.1, T1.1 (C)
/PA4: J1.1, T5.1 (C)
/PA5: J3.1
/PA6: J5.1, JP1.3 (B)
/PA7: J7.1
/PRN_D0: J18.1, J102.2
/PRN_D1: J19.1, J102.3
/PRN_D2: J20.1, J102.4
/PRN_D3: J24.1, J102.5
/PRN_D4: J23.1, J102.6
/PRN_D5: J22.1, J102.7
/PRN_D6: J21.1, J102.8
/PRN_D7: J16.1, J102.9
/R: J45.1, J101.3
/SYN H: J49.1, JP2.3 (B)
/SYN V: J50.1, JP3.2 (B)
/TAPE_IN: J35.1, J106.3
/TAPE_OUT: J33.1, J106.1
/j_down: J100.2, R2.1
/j_fire: J100.6, R5.1
/j_left: J100.3, R3.1
/j_pwr: J9.1, J100.7, T1.3 (E), T2.3 (E), T3.3 (E), T4.3 (E), T5.3 (E)
/j_right: J100.4, R4.1
/j_up: J100.1, R1.1
/~BUSY_NET: J39.1, J104.4, J105.4
/~LUM: J51.1, J103.1
/~PRN_ACK: J15.1, J102.10
/~PRN_STRB: J10.1, J102.1
/~SYNC: J44.1, J101.2
GND: C1.2, J12.1, J13.1, J14.1, J31.1, J34.1, J36.1, J38.1, J43.1, J52.1, J100.0 (PAD), J101.0 (PAD), J101.1, J102.0 (PAD), J102.18, J102.19, J102.20, J102.21, J102.22, J102.23, J102.24, J102.25, J103.2, J103.SH, J104.2, J104.SH, J105.2, J105.SH, J106.2, J106.SH, J107.2, J107.3, J108.2, JP1.1 (A), SW1.S1, SW1.S2, SW2.S1, SW2.S2
unnamed: F1.1, SW2.2 (B), SW2.5 (B)
unnamed: F1.2, J107.1
unnamed: J41.1, SW1.3 (C), SW1.6 (C)
unnamed: J42.1, SW1.2 (B), SW1.5 (B)
unnamed: J100.8, JP1.2 (C)
unnamed: C1.1, JP2.1 (A), R6.1
unnamed: J101.8, JP2.2 (C)
unnamed: J101.9, JP3.1 (A)
unnamed: J101.7, JP4.2 (B)
unnamed: R1.2, T1.2 (B)
unnamed: R2.2, T2.2 (B)
unnamed: R3.2, T3.2 (B)
unnamed: R4.2, T4.2 (B)
unnamed: R5.2, T5.2 (B)

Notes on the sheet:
Printer
Note: pin 8 is GND in a standard joystick port, pull-up in Elwro, this is the reason for using T1-T5 inverters.
Tape
Junet
Video
Note: J17 is left for mechanical reasons.
Reset / power
Note: PA7 is shorted to GND on the mainboard.
Joystick

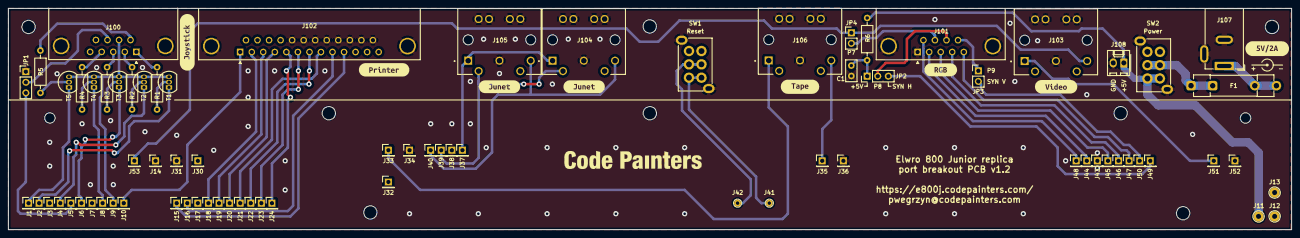
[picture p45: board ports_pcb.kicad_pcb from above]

Board: 2 copper layers, 308.0 x 53.1 mm, 92 parts (0 on the bottom side), 52 nets.

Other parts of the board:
IMG1: logo
MH1, MH5: mth25
MH2, MH3, MH4, MH6, MH7: mth32
kibuzzard-67F8F98E: G***; kibuzzard-67F8F98E
kibuzzard-67F911BA: G***; kibuzzard-67F911BA
kibuzzard-67F911F0, kibuzzard-67F911F0#2: G***; kibuzzard-67F911F0
kibuzzard-67F9119B: G***; kibuzzard-67F9119B
kibuzzard-67F91269: G***; kibuzzard-67F91269
kibuzzard-67F91296: G***; kibuzzard-67F91296
kibuzzard-67F91771: G***; kibuzzard-67F91771

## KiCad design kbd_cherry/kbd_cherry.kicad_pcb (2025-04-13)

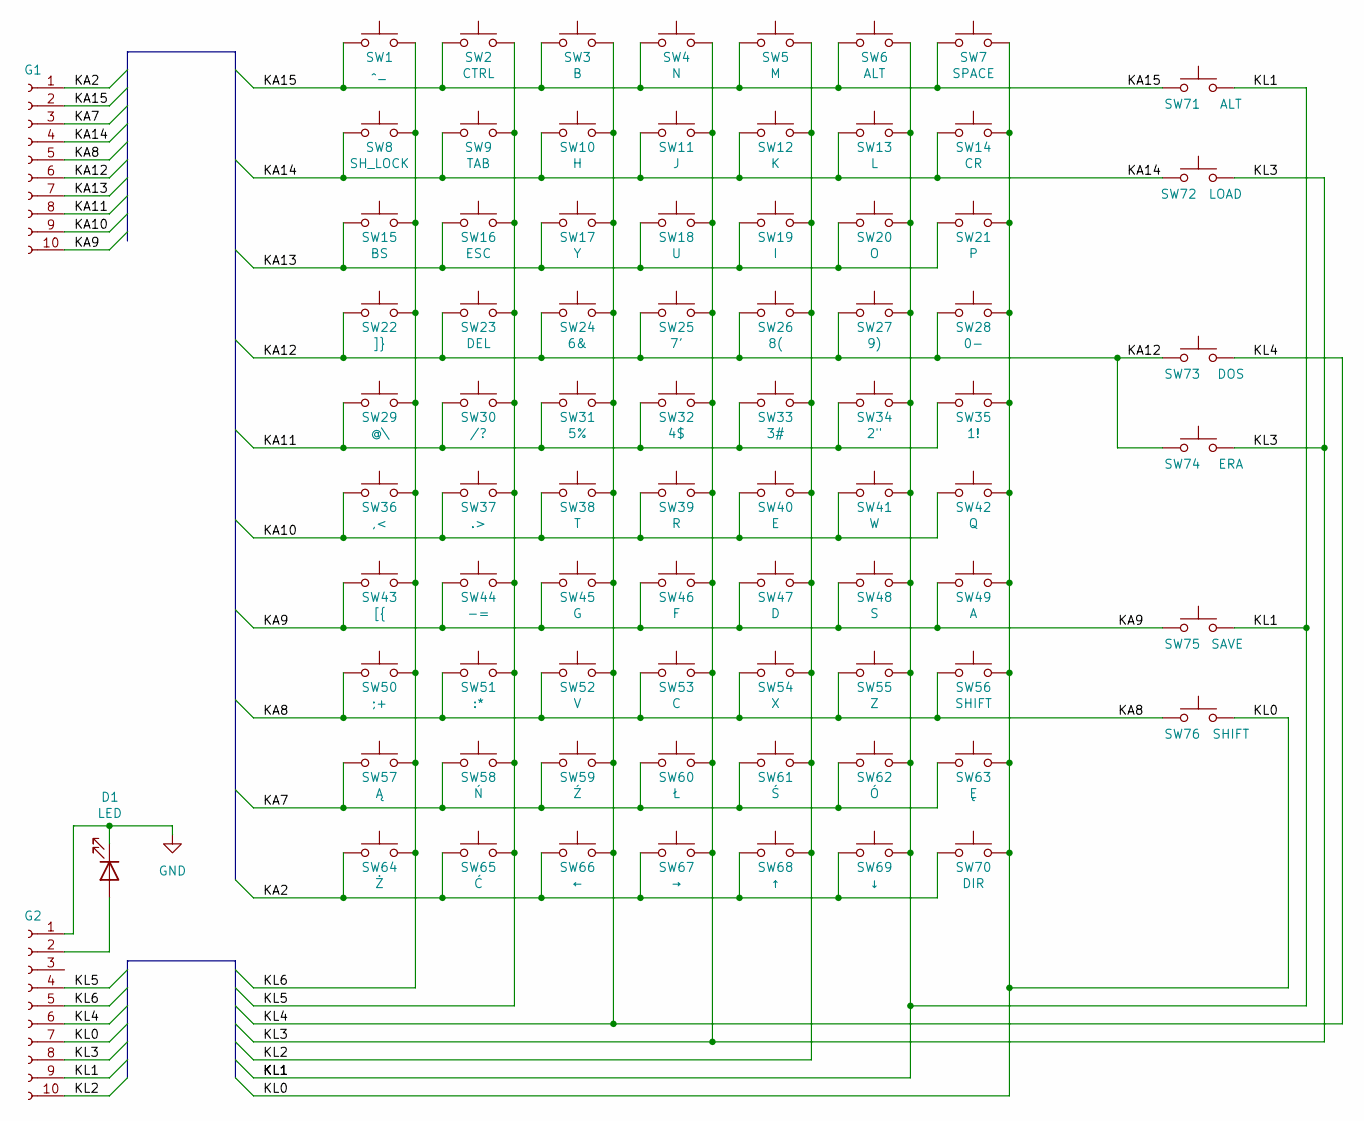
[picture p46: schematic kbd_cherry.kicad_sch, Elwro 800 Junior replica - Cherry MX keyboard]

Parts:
D1: LED; LED_D5.0mm
G1, G2: Conn_01x10_Socket; PinHeader_1x10_P2.54mm_Vertical
SW1: ^-; SW_Cherry_MX_1.00u_PCB
SW2: CTRL; SW_Cherry_MX_1.00u_PCB
SW3: B; SW_Cherry_MX_1.00u_PCB
SW4: N; SW_Cherry_MX_1.00u_PCB
SW5: M; SW_Cherry_MX_1.00u_PCB
SW6, SW71: ALT; SW_Cherry_MX_1.00u_PCB
SW7: SPACE; SW_Cherry_MX_6.25u_PCB
SW8: SH_LOCK; SW_Cherry_MX_1.00u_PCB
SW9: TAB; SW_Cherry_MX_1.00u_PCB
SW10: H; SW_Cherry_MX_1.00u_PCB
SW11: J; SW_Cherry_MX_1.00u_PCB
SW12: K; SW_Cherry_MX_1.00u_PCB
SW13: L; SW_Cherry_MX_1.00u_PCB
SW14: CR; SW_Cherry_MX_1.50u_PCB
SW15: BS; SW_Cherry_MX_1.00u_PCB
SW16: ESC; SW_Cherry_MX_1.00u_PCB
SW17: Y; SW_Cherry_MX_1.00u_PCB
SW18: U; SW_Cherry_MX_1.00u_PCB
SW19: I; SW_Cherry_MX_1.00u_PCB
SW20: O; SW_Cherry_MX_1.00u_PCB
SW21: P; SW_Cherry_MX_1.00u_PCB
SW22: ]}; SW_Cherry_MX_1.00u_PCB
SW23: DEL; SW_Cherry_MX_1.00u_PCB
SW24: 6&; SW_Cherry_MX_1.00u_PCB
SW25: 7'; SW_Cherry_MX_1.00u_PCB
SW26: 8(; SW_Cherry_MX_1.00u_PCB
SW27: 9); SW_Cherry_MX_1.00u_PCB
SW28: 0-; SW_Cherry_MX_1.00u_PCB
SW29: @\; SW_Cherry_MX_1.00u_PCB
SW30: /?; SW_Cherry_MX_1.00u_PCB
SW31: 5%; SW_Cherry_MX_1.00u_PCB
SW32: 4$; SW_Cherry_MX_1.00u_PCB
SW33: 3#; SW_Cherry_MX_1.00u_PCB
SW34: 2"; SW_Cherry_MX_1.00u_PCB
SW35: 1!; SW_Cherry_MX_1.00u_PCB
SW36: ,<; SW_Cherry_MX_1.00u_PCB
SW37: .>; SW_Cherry_MX_1.00u_PCB
SW38: T; SW_Cherry_MX_1.00u_PCB
SW39: R; SW_Cherry_MX_1.00u_PCB
SW40: E; SW_Cherry_MX_1.00u_PCB
SW41: W; SW_Cherry_MX_1.00u_PCB
SW42: Q; SW_Cherry_MX_1.00u_PCB
SW43: [{; SW_Cherry_MX_1.00u_PCB
SW44: -=; SW_Cherry_MX_1.00u_PCB
SW45: G; SW_Cherry_MX_1.00u_PCB
SW46: F; SW_Cherry_MX_1.00u_PCB
SW47: D; SW_Cherry_MX_1.00u_PCB
SW48: S; SW_Cherry_MX_1.00u_PCB
SW49: A; SW_Cherry_MX_1.00u_PCB
SW50: ;+; SW_Cherry_MX_1.00u_PCB
SW51: :*; SW_Cherry_MX_1.00u_PCB
SW52: V; SW_Cherry_MX_1.00u_PCB
SW53: C; SW_Cherry_MX_1.00u_PCB
SW54: X; SW_Cherry_MX_1.00u_PCB
SW55: Z; SW_Cherry_MX_1.00u_PCB
SW56: SHIFT; SW_Cherry_MX_1.00u_PCB
SW57: Ą; SW_Cherry_MX_1.00u_PCB
SW58: Ń; SW_Cherry_MX_1.00u_PCB
SW59: Ź; SW_Cherry_MX_1.00u_PCB
SW60: Ł; SW_Cherry_MX_1.00u_PCB
SW61: Ś; SW_Cherry_MX_1.00u_PCB
SW62: Ó; SW_Cherry_MX_1.00u_PCB
SW63: Ę; SW_Cherry_MX_1.00u_PCB
SW64: Ż; SW_Cherry_MX_1.00u_PCB
SW65: Ć; SW_Cherry_MX_1.00u_PCB
SW66: ←; SW_Cherry_MX_1.00u_PCB
SW67: →; SW_Cherry_MX_1.00u_PCB
SW68: ↑; SW_Cherry_MX_2.00u_PCB
SW69: ↓; SW_Cherry_MX_2.00u_PCB
SW70: DIR; SW_Cherry_MX_1.00u_PCB
SW72: LOAD; SW_Cherry_MX_1.00u_PCB
SW73: DOS; SW_Cherry_MX_1.00u_PCB
SW74: ERA; SW_Cherry_MX_1.00u_PCB
SW75: SAVE; SW_Cherry_MX_1.00u_PCB
SW76: SHIFT; SW_Cherry_MX_1.50u_PCB

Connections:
/KA2: G1.1, SW64.1, SW65.1, SW66.1, SW67.1, SW68.1, SW69.1, SW70.2
/KA7: G1.3, SW57.1, SW58.1, SW59.1, SW60.1, SW61.1, SW62.1, SW63.1
/KA8: G1.5, SW50.1, SW51.1, SW52.1, SW53.1, SW54.1, SW55.1, SW56.1, SW76.1
/KA9: G1.10, SW43.1, SW44.1, SW45.1, SW46.1, SW47.1, SW48.1, SW49.1, SW75.2
/KA10: G1.9, SW36.1, SW37.1, SW38.1, SW39.1, SW40.1, SW41.1, SW42.1
/KA11: G1.8, SW29.1, SW30.1, SW31.1, SW32.1, SW33.1, SW34.1, SW35.1
/KA12: G1.6, SW22.1, SW23.1, SW24.1, SW25.1, SW26.1, SW27.1, SW28.1, SW73.1, SW74.1
/KA13: G1.7, SW15.1, SW16.1, SW17.1, SW18.1, SW19.1, SW20.1, SW21.1
/KA14: G1.4, SW8.1, SW9.1, SW10.1, SW11.1, SW12.1, SW13.1, SW14.2, SW72.2
/KA15: G1.2, SW1.1, SW2.1, SW3.1, SW4.1, SW5.1, SW6.1, SW7.1, SW71.1
/KL0: G2.7, SW7.2, SW14.1, SW21.2, SW28.2, SW35.2, SW42.2, SW49.2, SW56.2, SW63.2, SW70.1, SW76.2
/KL1: G2.9, SW6.2, SW13.2, SW20.2, SW27.2, SW34.2, SW41.2, SW48.2, SW55.2, SW62.2, SW69.2, SW71.2, SW75.1
/KL2: G2.10, SW5.2, SW12.2, SW19.2, SW26.2, SW33.2, SW40.2, SW47.2, SW54.2, SW61.2, SW68.2
/KL3: G2.8, SW4.2, SW11.2, SW18.2, SW25.2, SW32.2, SW39.2, SW46.2, SW53.2, SW60.2, SW67.2, SW72.1, SW74.2
/KL4: G2.6, SW3.2, SW10.2, SW17.2, SW24.2, SW31.2, SW38.2, SW45.2, SW52.2, SW59.2, SW66.2, SW73.2
/KL5: G2.4, SW2.2, SW9.2, SW16.2, SW23.2, SW30.2, SW37.2, SW44.2, SW51.2, SW58.2, SW65.2
/KL6: G2.5, SW1.2, SW8.2, SW15.2, SW22.2, SW29.2, SW36.2, SW43.2, SW50.2, SW57.2, SW64.2
GND: D1.1 (K), G2.1
unnamed: D1.2 (A), G2.2

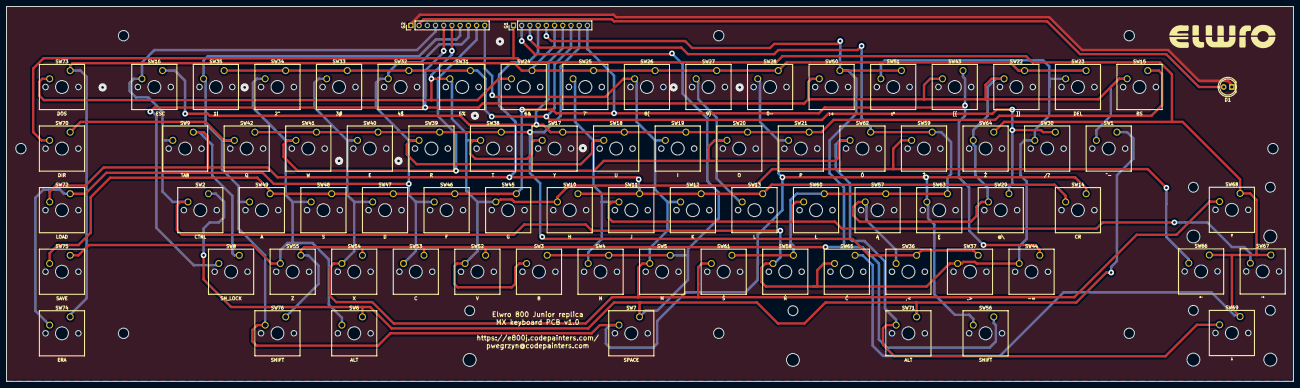
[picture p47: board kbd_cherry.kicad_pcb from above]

Board: 2 copper layers, 398.1 x 116.0 mm, 87 parts (0 on the bottom side), 19 nets.

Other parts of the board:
MH1, MH2, MH3, MH4, MH5, MH6, MH7, MH8: MountingHole_3.2mm_M3_DIN965

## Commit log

2025-04-07 Imported ports_pcb v1.0
    [CUI_SDS-50J.step, DCJ200-10-A-K1-K.step, PS-22F03.step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]
2025-04-07 Imported keyboard v1.0
    [kbd_cherry.kicad_pcb, kbd_cherry.kicad_sch, switch.step]
2025-04-07 Mainboard rev C 1.0 imported
    [addr_dec.kicad_sch, clock.kicad_sch, cpu.kicad_sch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]
2025-04-07 Let's keep previous name.
    [addr_dec.kicad_sch, clock.kicad_sch, cpu.kicad_sch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]
2025-04-09 ports_pcb: converted to KiCAD 9, fixed 3d models (#1)
    [DSUB-25_Female_Horizontal_P2.77x2.84mm_EdgePinOffset7.70mm_Housed_MountingHolesOffset9.12mm.step, DSUB-9_Female_Horizontal_P2.77x2.84mm_EdgePinOffset7.70mm_Hou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]
2025-04-09 Ports PCB: reworked joy (#8) and video (#10)
    [ports_pcb.kicad_pcb, ports_pcb.kicad_sch]
2025-04-11 ports_pcb: added fuse, aux power connector, changed DIN 3d model
    [CUI_SDS-50J.step, DIN5_PCB_DELTRON_671-0500.step, FuseHolder.step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]
2025-04-11 ports_pcb: fixed a typo in schematic title
    [ports_pcb.kicad_sch]
2025-04-11 ports_pcb: labels replaced with thicker font (#11)
    [ports_pcb.kicad_pcb]
2025-04-12 ports_pcb: not sure why, but KiCAD added fon thickness everywhere
    [ports_pcb.kicad_pcb]
2025-04-12 Reworking keyboard directory
    [kbd_cherry.kicad_pcb, kbd_cherry.kicad_sch, switch.step]
2025-04-12 kbd_cherry: converted to KiCAD 9, schematic size reduced to A4
    [kbd_cherry.kicad_pcb, kbd_cherry.kicad_sch]
2025-04-12 kbd_cherry: schematics as PDFs
2025-04-13 ports_pcb: excluded Jx headers from BOM
    [ports_pcb.kicad_pcb, ports_pcb.kicad_sch]
2025-04-13 kbd_cherry: switched to local 3d models
    [LED_D5.0mm.step, PinHeader_1x10_P2.54mm_Vertical.step, kbd_cherry.kicad_pcb]
2025-04-16 mainboard: converted to KiCAD9, vendored 3d models
    [C_Disc_D3.0mm_W1.6mm_P2.50mm.step, C_Disc_D4.3mm_W1.9mm_P5.00mm.step, DIP-14_W7.62mm.step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]
2025-04-16 mainboard: schematics updated to v9.0
    [addr_dec.kicad_sch, clock.kicad_sch, cpu.kicad_sch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]
2025-04-17 ports_pcb: gerbers v1.1
2025-04-17 Moving gerbers - let's keep the dir-per-pcb scheme
2025-04-18 mianboard: more fixes (#3, #4, #6)
    - #3 - fixed GWP10 (keyboard connector) footprint pitch
    - #4 - increased Z3 jumper hole diameters
    - #6 - increased silkscreen circles diameter and thickness
    [D_DO-35_SOD27_P10.16mm_Horizontal.step, junet.kicad_sch]
2025-04-18 mainboard: post-chages clearance issues fixed
    [junet.kicad_sch]
2025-04-18 mainboard: minor fixes
    [clock.kicad_sch, pio.kicad_sch, timing.kicad_sch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]
2025-04-18 mainboard: bom updated
2025-04-18 mainboard: gerber files
2025-05-19 ports_pcb: added jP4 jumper to allow disconnecting FON (#13)
    [ports_pcb.kicad_pcb, ports_pcb.kicad_sch]
2025-05-19 prots_pcb: minor tweaks, v1.2
    [ports_pcb.kicad_pcb]
2025-05-19 ports_pcb: schematics + README update for 1.2
    [ports_pcb.kicad_sch]
2025-05-19 DRC exclusions
    - fiducial collision with GND track (as on original board)
    - workaround for KiCad bug (net with &lt; or &gt; in name casuses false DRC alarm)
2025-07-21 Marked unpopulated components properly (see #14)
    [clock.kicad_sch, kbd_tape.kicad_sch, power.kicad_sch]
2025-08-21 Adding some assembler tests (color bars)

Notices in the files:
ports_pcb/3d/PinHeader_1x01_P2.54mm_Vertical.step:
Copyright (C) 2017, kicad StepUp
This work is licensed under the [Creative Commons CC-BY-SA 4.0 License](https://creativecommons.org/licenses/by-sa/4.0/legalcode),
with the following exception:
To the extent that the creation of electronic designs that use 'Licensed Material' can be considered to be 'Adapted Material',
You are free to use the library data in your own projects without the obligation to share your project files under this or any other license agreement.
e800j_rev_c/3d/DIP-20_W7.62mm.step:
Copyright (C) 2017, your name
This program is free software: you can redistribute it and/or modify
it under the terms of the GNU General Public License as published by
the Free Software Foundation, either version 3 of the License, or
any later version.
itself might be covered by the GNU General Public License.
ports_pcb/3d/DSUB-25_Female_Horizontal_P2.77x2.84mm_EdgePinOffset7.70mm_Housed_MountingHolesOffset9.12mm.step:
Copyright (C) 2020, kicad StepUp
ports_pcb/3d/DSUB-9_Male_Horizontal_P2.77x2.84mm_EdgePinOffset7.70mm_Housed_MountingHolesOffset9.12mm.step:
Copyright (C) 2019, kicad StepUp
